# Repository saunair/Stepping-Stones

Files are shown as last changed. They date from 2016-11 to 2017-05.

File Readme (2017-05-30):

The code is launched in the master PC by the following commands in different terminals
roslaunch morpheus_skates stepping_stones.launch
rosrun morpheus_skates take_user_input.py
rosrun morpheus_skates shoe_size_input.py

Calibration routine:
roslaunch morpheus_skates calibration_arduino.py

The folder structure is created in a way that all the components are separate from each other
Arduino contains all the object oriented code that runs in each skate
CATKIN workspace contains all the ROS code 
Matlab contains the ROSBAGs, ROSBAG parsing scripts and some simulation files
Mechanical/CAD has all the CAD files of the skates 
Electrical Contains the PCB schematic and layouts used for power distribution and sensing

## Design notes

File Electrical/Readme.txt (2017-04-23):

Schematic and Layout Designs for Power distribution and sensing suite PCB.

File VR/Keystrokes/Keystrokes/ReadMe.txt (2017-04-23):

========================================================================
    CONSOLE APPLICATION : Keystrokes Project Overview
========================================================================

AppWizard has created this Keystrokes application for you.

This file contains a summary of what you will find in each of the files that
make up your Keystrokes application.

Keystrokes.vcxproj
    This is the main project file for VC++ projects generated using an Application Wizard.
    It contains information about the version of Visual C++ that generated the file, and
    information about the platforms, configurations, and project features selected with the
    Application Wizard.

Keystrokes.vcxproj.filters
    This is the filters file for VC++ projects generated using an Application Wizard. 
    It contains information about the association between the files in your project 
    and the filters. This association is used in the IDE to show grouping of files with
    similar extensions under a specific node (for e.g. ".cpp" files are associated with the
    "Source Files" filter).

Keystrokes.cpp
    This is the main application source file.

/////////////////////////////////////////////////////////////////////////////
Other standard files:

StdAfx.h, StdAfx.cpp
    These files are used to build a precompiled header (PCH) file
    named Keystrokes.pch and a precompiled types file named StdAfx.obj.

/////////////////////////////////////////////////////////////////////////////
Other notes:

AppWizard uses "TODO:" comments to indicate parts of the source code you
should add to or customize.

/////////////////////////////////////////////////////////////////////////////

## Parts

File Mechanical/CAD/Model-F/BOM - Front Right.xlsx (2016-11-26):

Bill of Materials for front half
Sl. No. | Item | Qty | Inventory | Remarks | Notes
1 | Base plate | 2 |  | Manufacture from stock plate
2 | Top plate | 2 |  | Manufacture from stock plate
3 | Force sensor foundation | 2 |  | Manufacture from stock plate
4 | Aux shaft | 2 |  | Manufacture from stock cylinder
5 | Motor-Gearbox adapter | 2 |  | Manufacture from stock cylinder
6 | Guide rail | 2 |  | 3D print
7 | Bearing mount | 2 |  | 3D print
8 | Gearbox mount | 2 |  | 3D print
9 | Ball caster mount | 6 |  | 3D print
10 | Force sensor locator | 2 |  | 3D print
11 | PCB mount | 2 |  | 3D print
12 | PCB | 2 |  | Manufacture (outsourced)
13 | Arduino | 2
14 | Wheel | 2 |  | Purchased - Banebots
15 | Wheel hub | 2 |  | Purchased - Banebots
16 | Gearbox | 2 |  | Purchased - Banebots
17 | Motor | 2 |  | Purchased - T-Motor
18 | Encoder | 2
19 | ESC | 2
20 | Force sensor | 4
21 | Ball casters | 6 |  | McMaster
22 | Bearing | 2 |  | McMaster
23 | Screw 10-32x1" | 20 |  |  | Including 2 extra for force sensor foundation
24 | Hex nut 10-32 | 12 |  |  | Including 2 extra for force sensor foundation
25 | Screw 4-40x3/8" | 42 |  |  | Ball caster mount
26 | Screw 4-40x1/2" | 28 |  |  | Guide rail, Bearing mount, Gearbox mount
26 | Grub screw 4-40x1/4" | 4 |  |  | Aux shaft
26 | Threaded inserts 4-40 | 70
Bill of Materials Back right half
Sl. No. | Item | Qty | Inventory | Remarks | Notes
1 | Base plate | 1 |  | Manufacture from stock plate | Might have to find more stock
2 | Top plate | 1 |  | Manufacture from stock plate
3 | Force sensor foundation | 1 |  | Manufacture from stock plate
4 | Aux shaft | 1 |  | Manufacture from stock cylinder
5 | Motor-Gearbox adapter | 1 |  | Manufacture from stock cylinder
6 | Guide rail | 1 |  | 3D print
7 | Bearing mount | 1 |  | 3D print
8 | Gearbox mount | 1 |  | 3D print
9 | Ball caster mount | 3 |  | 3D print
10 | Force sensor locator | 1 |  | 3D print
11 | Wheel | 1 |  | Purchased - Banebots
12 | Wheel hub | 1 |  | Purchased - Banebots
13 | Gearbox | 1 |  | Purchased - Banebots
14 | Motor | 1 |  | Purchased - T-Motor
15 | Encoder | 1
16 | ESC | 1
17 | Force sensor | 1
18 | Ball casters | 3 |  | McMaster
19 | Bearing | 1 |  | McMaster
20 | Screw 10-32x1" | 10 |  |  | Including 2 extra for force sensor foundation
21 | Hex nut 10-32 | 6 |  |  | Including 2 extra for force sensor foundation
22 | Screw 4-40x3/8" | 21 |  |  | Ball caster mount
23 | Screw 4-40x1/2" | 14 |  |  | Guide rail, Bearing mount, Gearbox mount
24 | Grub screw 4-40x1/4" | 2 |  |  | Aux shaft
25 | Threaded inserts 4-40 | 35
26 | IMU |  |  |  | Mounting needs to be discussed

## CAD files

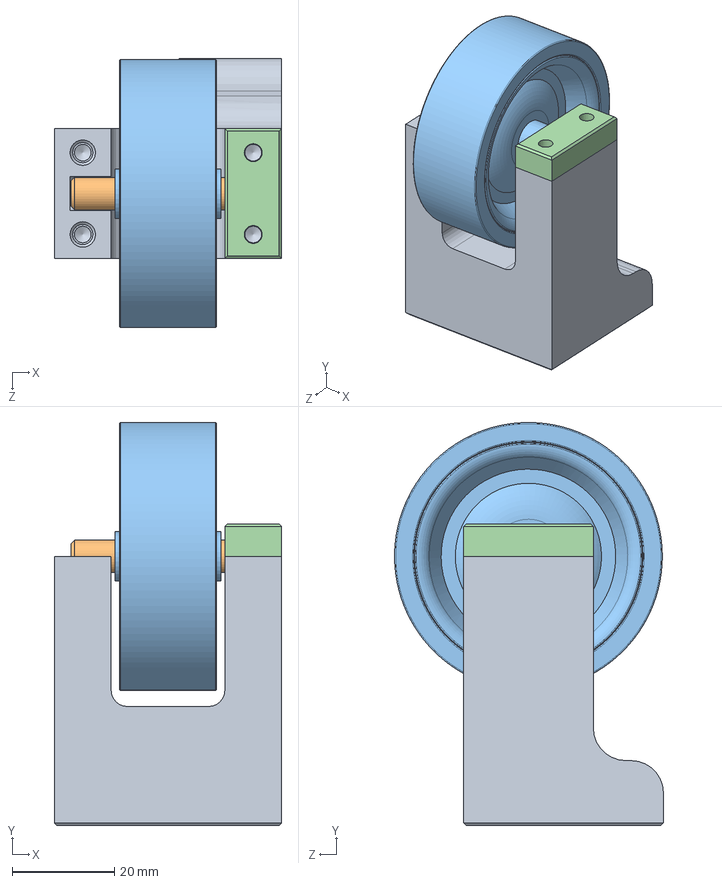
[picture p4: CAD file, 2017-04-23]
Mechanical/CAD/Model-S/ss_ms_v1_Skate_Wheel_Assembly_Mirrored.SLDASM
44.5 x 78.8 x 52.6 mm
ss_ms_v1_SkateWheelForkMirrored
ss_ms_v0_DowelPinShaft
ss_ms_v0_SkateWheel
ss_ms_v1_SkateWheelMount_Outer

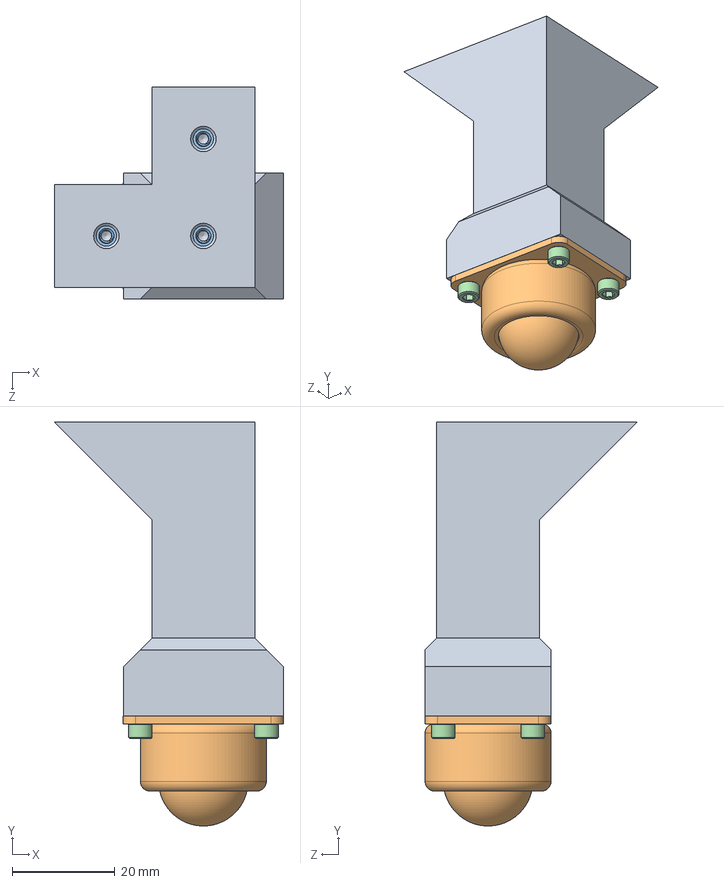
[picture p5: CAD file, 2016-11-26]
Mechanical/CAD/Model-F/Caster Supports/ss_mf_v1_BallCasterAssembly2.SLDASM
44.8 x 78.8 x 41.4 mm
ss_mf_v1_BallCasterMount2
ss_mf_v0_BallCaster
ss_mf_v0_ThreadedInsert440 x 7
ss_mf_v0_Screw_4-40x0.375 x 4

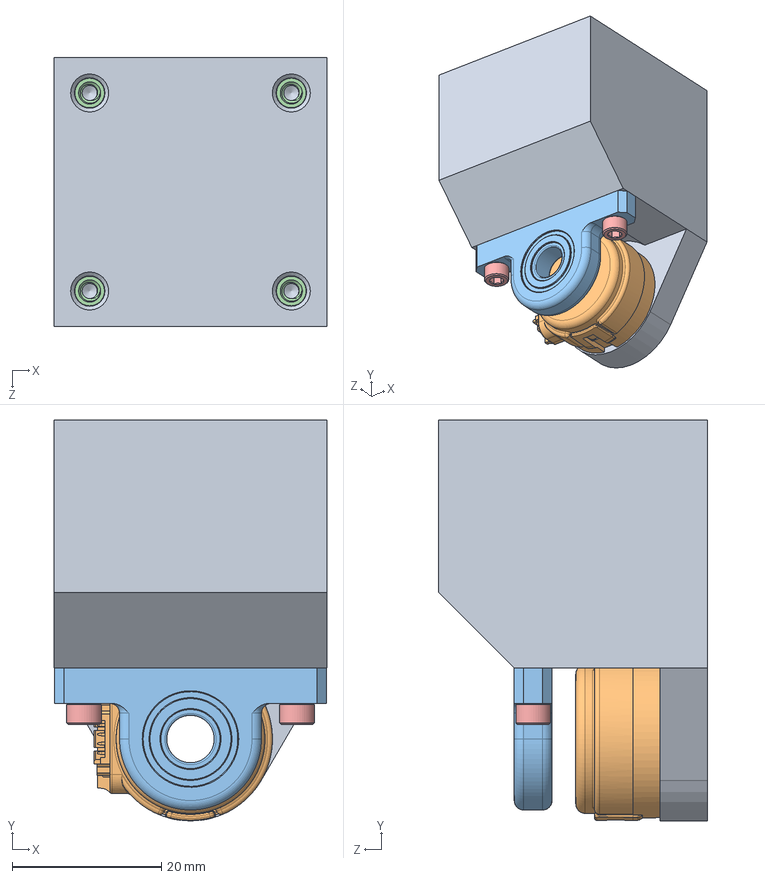
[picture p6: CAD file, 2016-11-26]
Mechanical/CAD/Model-F/Drive Train/ss_mf_v1_EncoderBearingAssembly.SLDASM
36.6 x 53.8 x 36.1 mm
ss_mf_v1_BearingMount
ss_mf_v0_Encoder
ss_mf_v0_Bearing
ss_mf_v0_ThreadedInsert440 x 6
ss_mf_v0_Screw_4-40x0.5 x 2

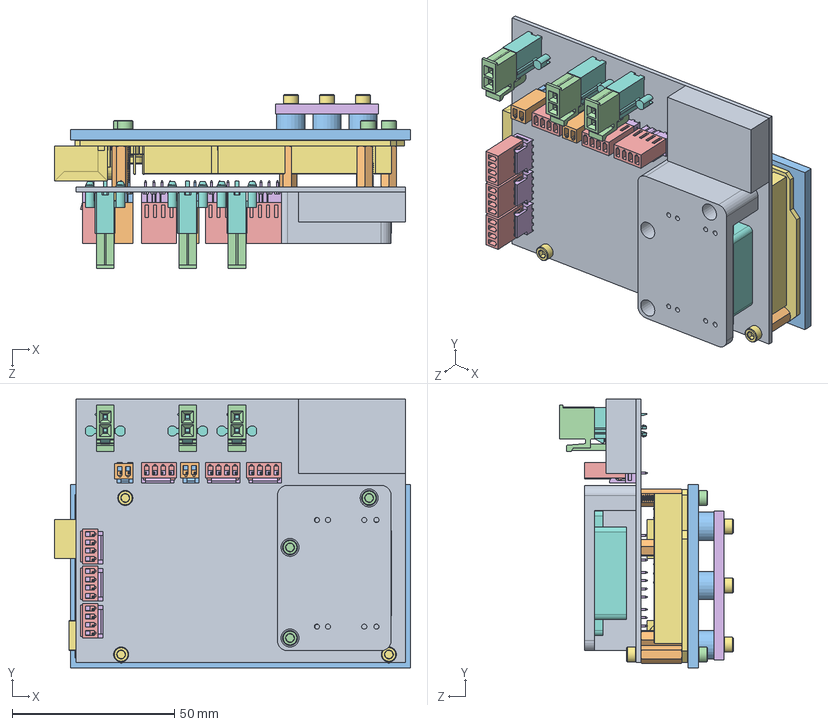
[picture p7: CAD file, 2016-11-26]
Mechanical/CAD/Model-F/PCB/ss_mf_v1_ArduinoMainboardAssembly.SLDASM
109.8 x 82.9 x 53.6 mm
ss_mf_v1_MainboardPCB
ss_mf_v0_ArduinoMega
UWS
ss_mf_v0_Standoff_4-40x0.5 x 6
ss_mf_v1_pcbMountP2
ss_mf_v0_Screw_4-40x0.5 x 7
ss_mf_v0_ThreadedInsert440 x 4
ss_mf_v1_pcbMountP1
ss_mf_v0_Screw_4-40x0.375 x 7
ss_mf_v0_IMU
ss_mf_v1_imuMount

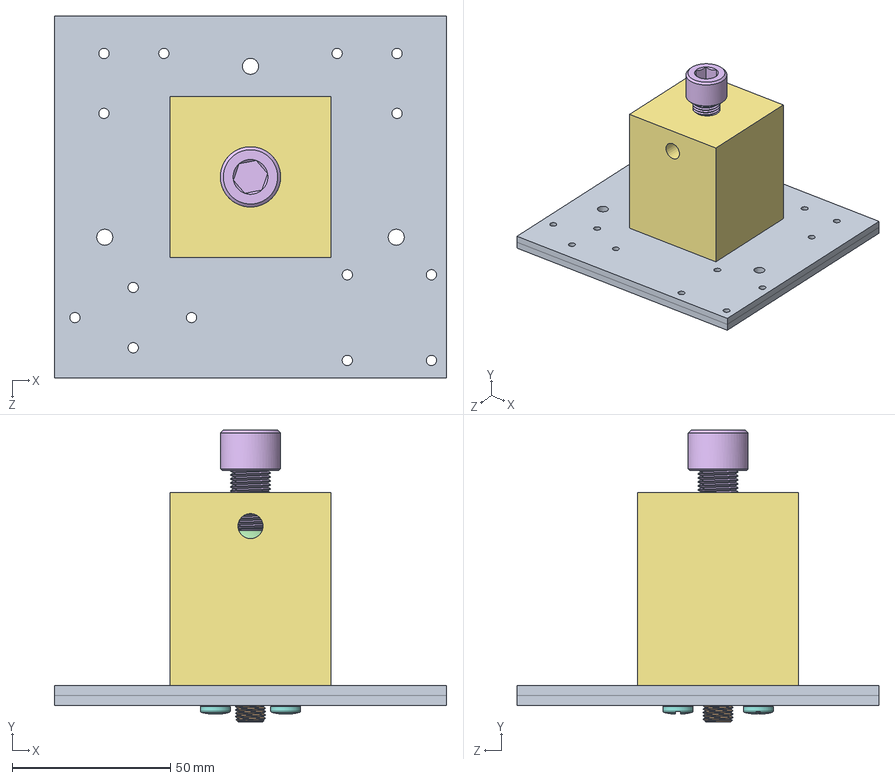
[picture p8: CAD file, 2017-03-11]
Mechanical/CAD/Force Calibration Rig/Rear Force Calibration Rig.SLDASM
123.8 x 92.2 x 114.3 mm
ss_mf_v1_BasePlateBack x 2
92620A654_HIGH-STRENGTH GRADE 8 STEEL CAP SCREW
92141A031_TYPE 18-8 STAINLESS STEEL FLAT WASHER x 2
92949A749_18-8 SS BUTTON-HEAD SOCKET CAP SCREW
9573K620_MEDIUM LOAD CHROME-SILICON STEEL DIE SPRING
92196A384_18-8 STAINLESS STEEL SOCKET HEAD CAP SCREW
Rear Skate Rig Block
90283A831_ZINC-PLTD STL PAN HEAD SLOTTED MACHINE SCREW x 4

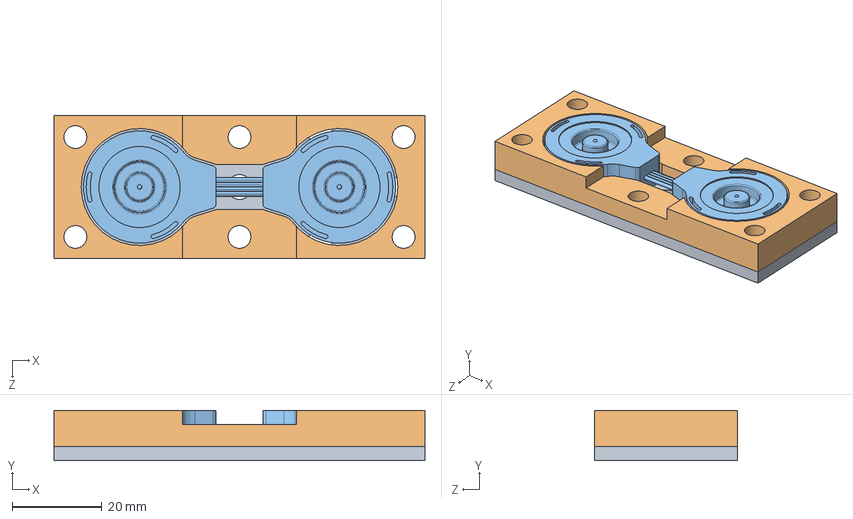
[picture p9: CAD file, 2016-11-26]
Mechanical/CAD/Model-F/Force Sensing/ss_mf_v1_DualForceAssembly.SLDASM
82.5 x 11.2 x 31.8 mm
ss_mf_v1_ForceSensorFoundationDual
ss_mf_v1_ForceSensorLocatorDual
ss_mf_v0_ForceSensor x 2

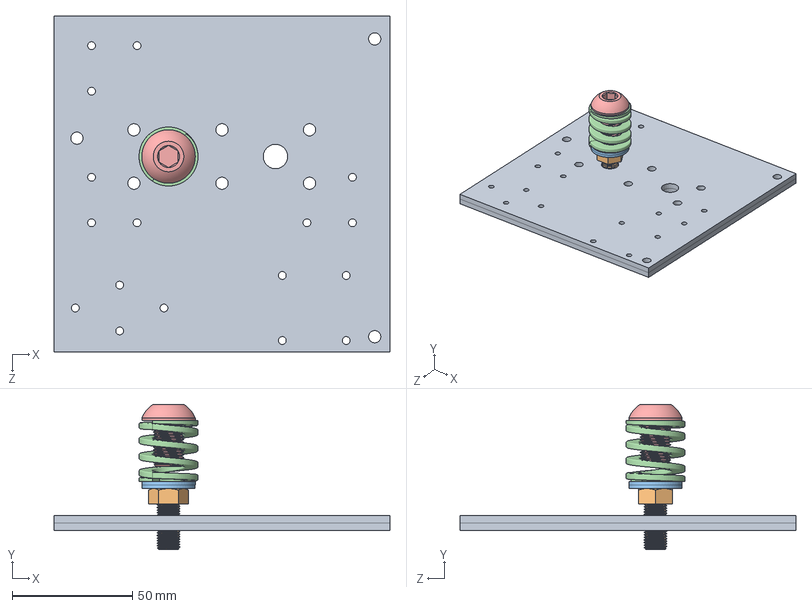
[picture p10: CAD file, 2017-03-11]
Mechanical/CAD/Force Calibration Rig/Force Calibration Rig.SLDASM
139.7 x 60.4 x 139.7 mm
ss_mf_v1_BasePlate x 2
92620A654_HIGH-STRENGTH GRADE 8 STEEL CAP SCREW
92141A031_TYPE 18-8 STAINLESS STEEL FLAT WASHER x 2
9573K620_MEDIUM LOAD CHROME-SILICON STEEL DIE SPRING
92949A749_18-8 SS BUTTON-HEAD SOCKET CAP SCREW

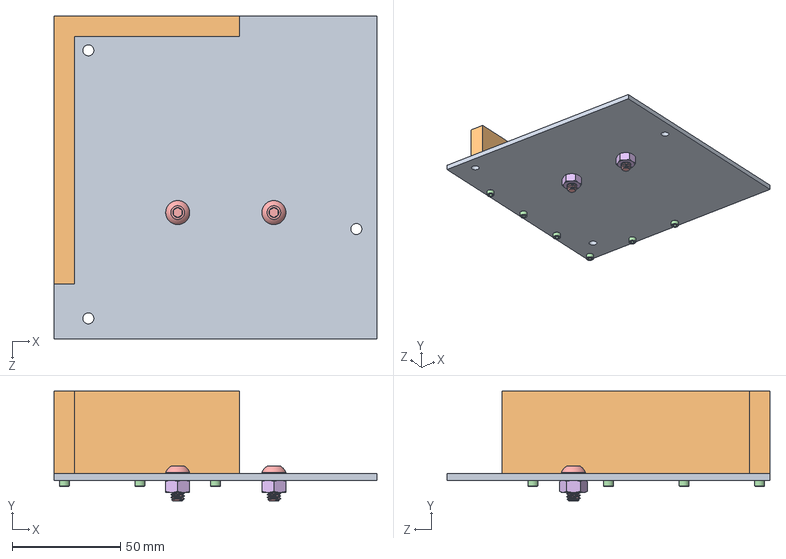
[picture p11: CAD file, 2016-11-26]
Mechanical/CAD/Model-F/ss_mf_v1_Top_Plate_Assembly.SLDASM
149.2 x 50.8 x 149.2 mm
ss_mf_v1_TopPlate
ss_mf_v1_GuideRail
ss_mf_v0_ThreadedInsert440 x 6
ss_mf_v0_Screw_4-40x0.375 x 6
ss_mf_v0_Screw_1_4-20x0.5 x 2
ss_mf_v0_HexNut_1_4-20 x 2

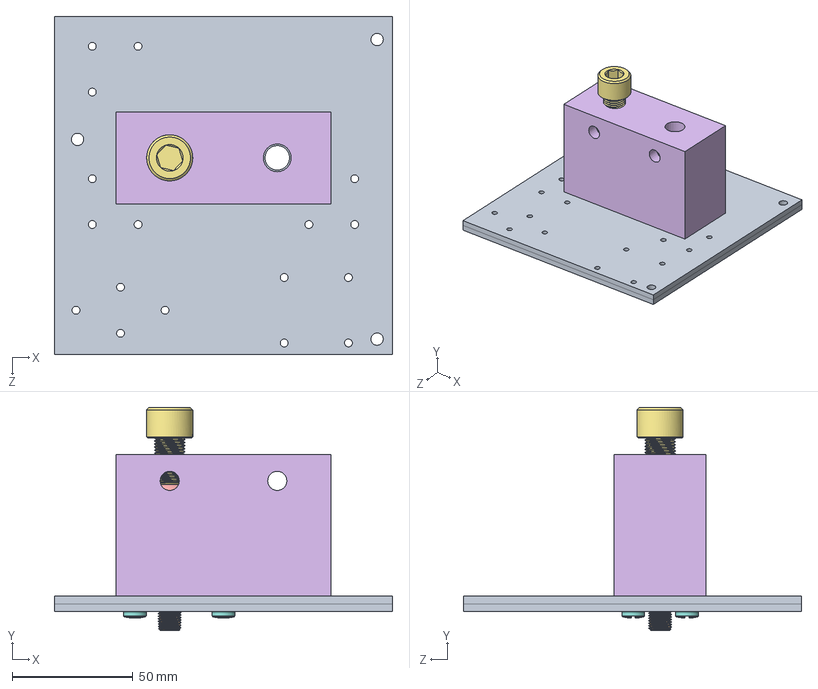
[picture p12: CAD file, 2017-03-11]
Mechanical/CAD/Force Calibration Rig/Front Force Calibration Rig.SLDASM
139.7 x 92.2 x 139.7 mm
ss_mf_v1_BasePlate x 2
92620A654_HIGH-STRENGTH GRADE 8 STEEL CAP SCREW
92141A031_TYPE 18-8 STAINLESS STEEL FLAT WASHER x 2
9573K620_MEDIUM LOAD CHROME-SILICON STEEL DIE SPRING
92949A749_18-8 SS BUTTON-HEAD SOCKET CAP SCREW
Front Skate Rig Block
92196A384_18-8 STAINLESS STEEL SOCKET HEAD CAP SCREW
90283A831_ZINC-PLTD STL PAN HEAD SLOTTED MACHINE SCREW x 4

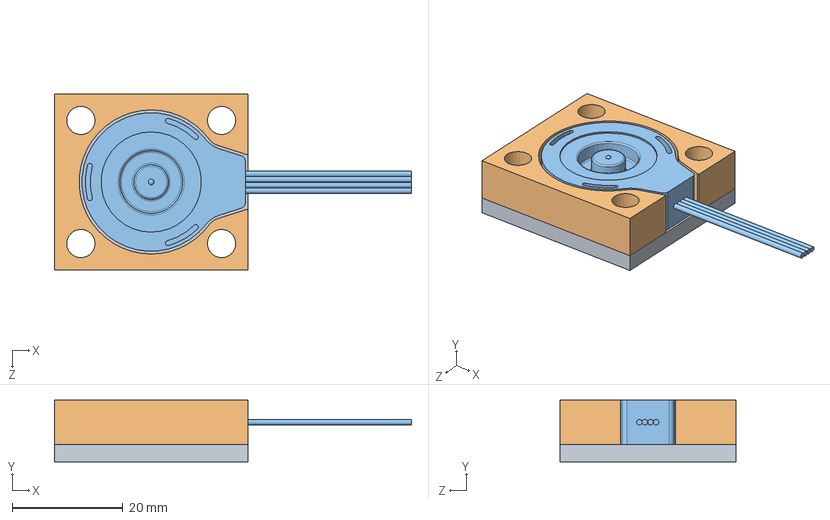
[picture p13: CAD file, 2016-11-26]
Mechanical/CAD/Model-F/Force Sensing/ss_mf_v1_SingleForceAssembly.SLDASM
64.5 x 11.2 x 31.8 mm
ss_mf_v1_ForceSensorFoundationSingle
ss_mf_v1_ForceSensorLocatorSingle
ss_mf_v0_ForceSensor

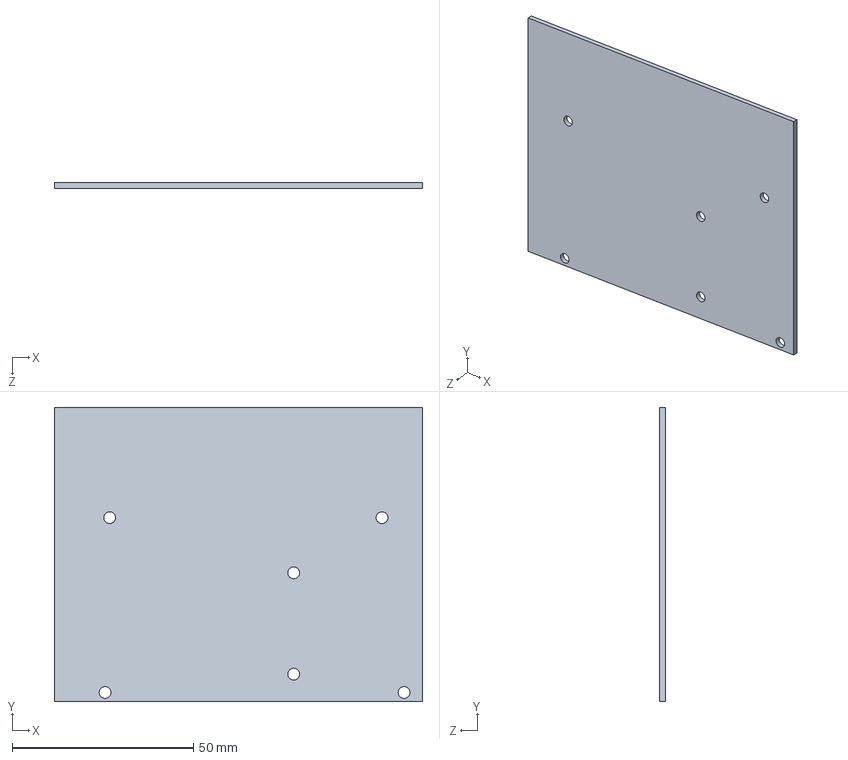
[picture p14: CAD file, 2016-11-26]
Mechanical/CAD/Model-F/PCB/ss_mf_v1_MainboardPCB.SLDPRT
101.6 x 81.3 x 1.52 mm

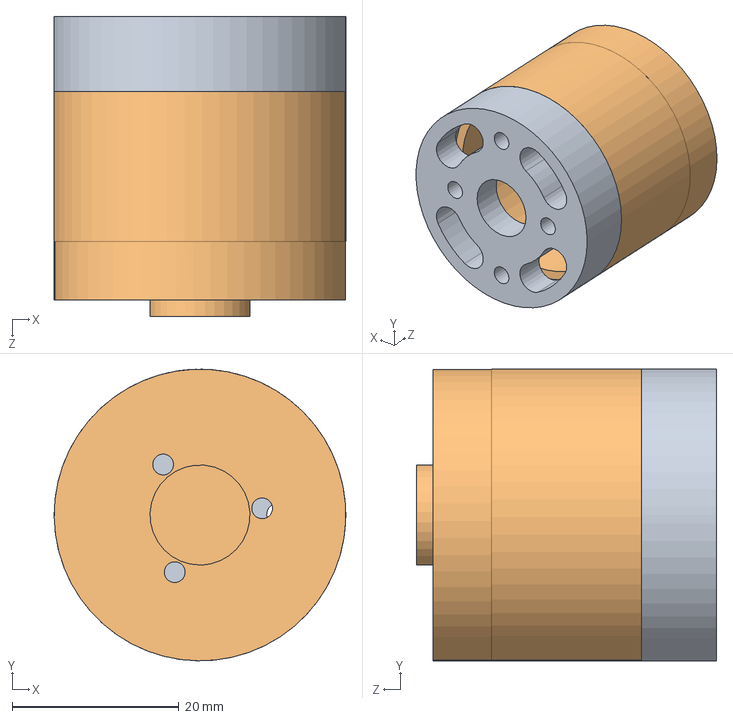
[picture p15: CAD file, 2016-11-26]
Mechanical/CAD/Model-F/Drive Train/ss_mf_v0_Motor.SLDASM
35.0 x 35.0 x 36.0 mm
ss_mf_v0_MotorBack
ss_mf_v0_MotorFront

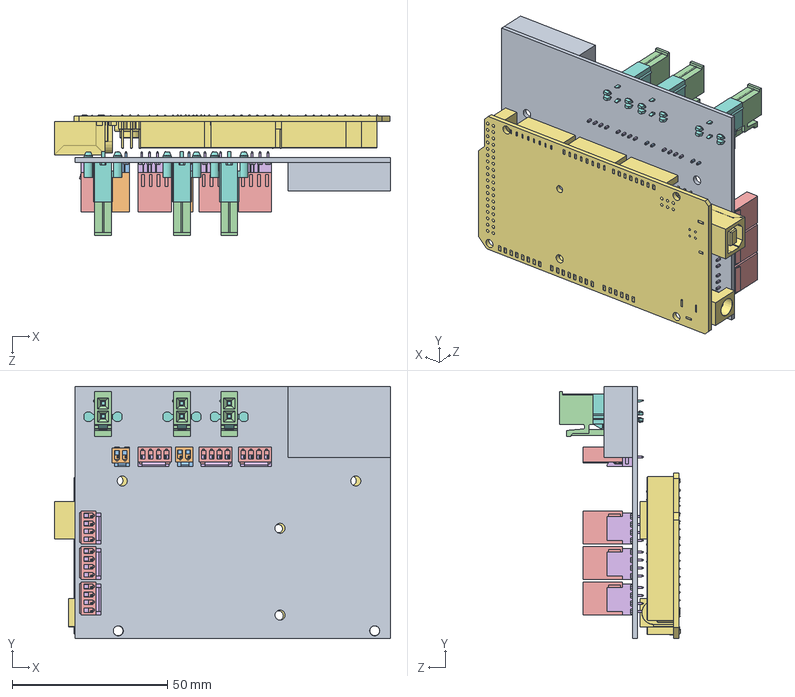
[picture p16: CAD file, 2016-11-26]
Mechanical/CAD/Model-F/PCB/ss_mf_v1_ArduinoMainboard.SLDASM
108.2 x 81.3 x 38.9 mm
ss_mf_v1_MainboardPCB
ss_mf_v0_ArduinoMega
UWS

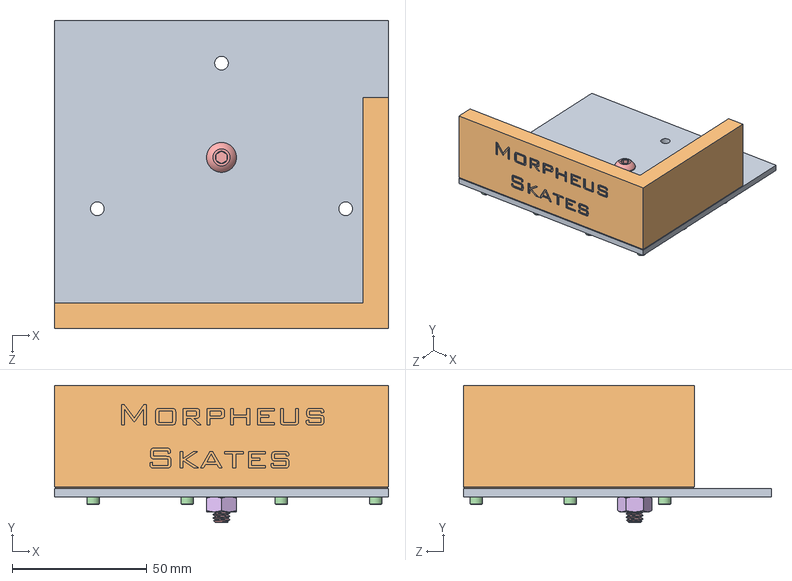
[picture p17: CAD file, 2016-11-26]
Mechanical/CAD/Model-F/ss_mf_v1_BL_Top_Plate_Assembly.SLDASM
123.8 x 50.8 x 114.3 mm
ss_mf_v1_TopPlateBack
ss_mf_v1_GuideRail_BL
ss_mf_v0_ThreadedInsert440 x 6
ss_mf_v0_Screw_4-40x0.5 x 6
ss_mf_v0_Screw_1_4-20x0.5
ss_mf_v0_HexNut_1_4-20

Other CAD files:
Mechanical/CAD/Model-S/ss_ms_v1_Skate_Wheel_Assembly.SLDASM
Mechanical/CAD/Model-F/Caster Supports/ss_mf_v1_BallCasterAssembly.SLDASM
Mechanical/CAD/Model-F/ss_mf_v1_FR_Top_Plate_Assembly.SLDASM
Mechanical/CAD/Model-F/Drive Train/ss_mf_v1_DriveTrainAssembly.SLDASM
Mechanical/CAD/Force Calibration Rig/90283A831_ZINC-PLTD STL PAN HEAD SLOTTED MACHINE SCREW.SLDPRT
Mechanical/CAD/Force Calibration Rig/91841A195_TYPE 18-8 STAINLESS STEEL HEX NUT.SLDPRT
Mechanical/CAD/Force Calibration Rig/92141A031_TYPE 18-8 STAINLESS STEEL FLAT WASHER.SLDPRT
Mechanical/CAD/Force Calibration Rig/92196A384_18-8 STAINLESS STEEL SOCKET HEAD CAP SCREW.SLDPRT
Mechanical/CAD/Force Calibration Rig/92210A304_18-8 STAINLESS STEEL FLAT-HEAD SCKT CAP SCREW.SLDPRT
Mechanical/CAD/Force Calibration Rig/92620A654_HIGH-STRENGTH GRADE 8 STEEL CAP SCREW.SLDPRT
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

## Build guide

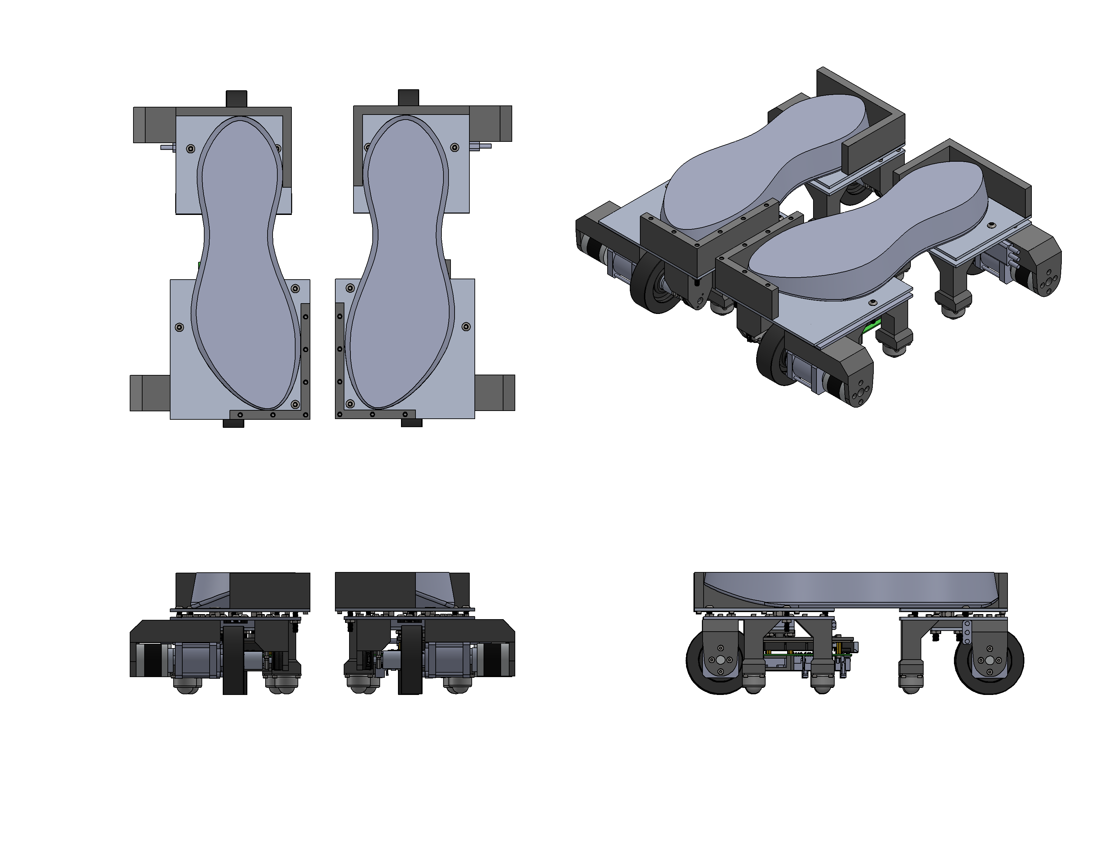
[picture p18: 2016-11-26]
Mechanical/CAD/Model-F/ss_mf_v1_Shoe_Test_Assembly.PNG

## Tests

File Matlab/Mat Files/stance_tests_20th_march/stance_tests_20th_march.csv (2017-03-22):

Time | LeftNormalFrontOuter | LeftNormalFrontInner | LeftNormalRear | RightNormalFrontOuter | RightNormalFrontInner | RightNormalRear | RightNormalTotal | LeftNormalTotal | NormalTotal | Label
-1490064341.57929 | 0.0568256229162216 | 0.121759116649628 | 0.313521653413773 | 0.00944731291383505 | 0.183949649333954 | 0.327496975660324 | 0.520893931388855 | 0.492106378078461 | 1.01300036907196 | 1
-1490064341.57929 | 0.0553924106061459 | 0.121759116649628 | 0.313521653413773 | 0.0108032403513789 | 0.185449823737144 | 0.325034290552139 | 0.521287322044373 | 0.490673154592514 | 1.01196050643921 | 1
-1490064341.57929 | 0.0568256229162216 | 0.123117178678513 | 0.31218209862709 | 0.00944731291383505 | 0.186949983239174 | 0.322571575641632 | 0.518968880176544 | 0.492124885320663 | 1.01109373569489 | 1
-1490064341.57929 | 0.0553924106061459 | 0.123117178678513 | 0.313521653413773 | 0.0108032403513789 | 0.188450157642365 | 0.320108860731125 | 0.519362270832062 | 0.492031216621399 | 1.01139354705811 | 1
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

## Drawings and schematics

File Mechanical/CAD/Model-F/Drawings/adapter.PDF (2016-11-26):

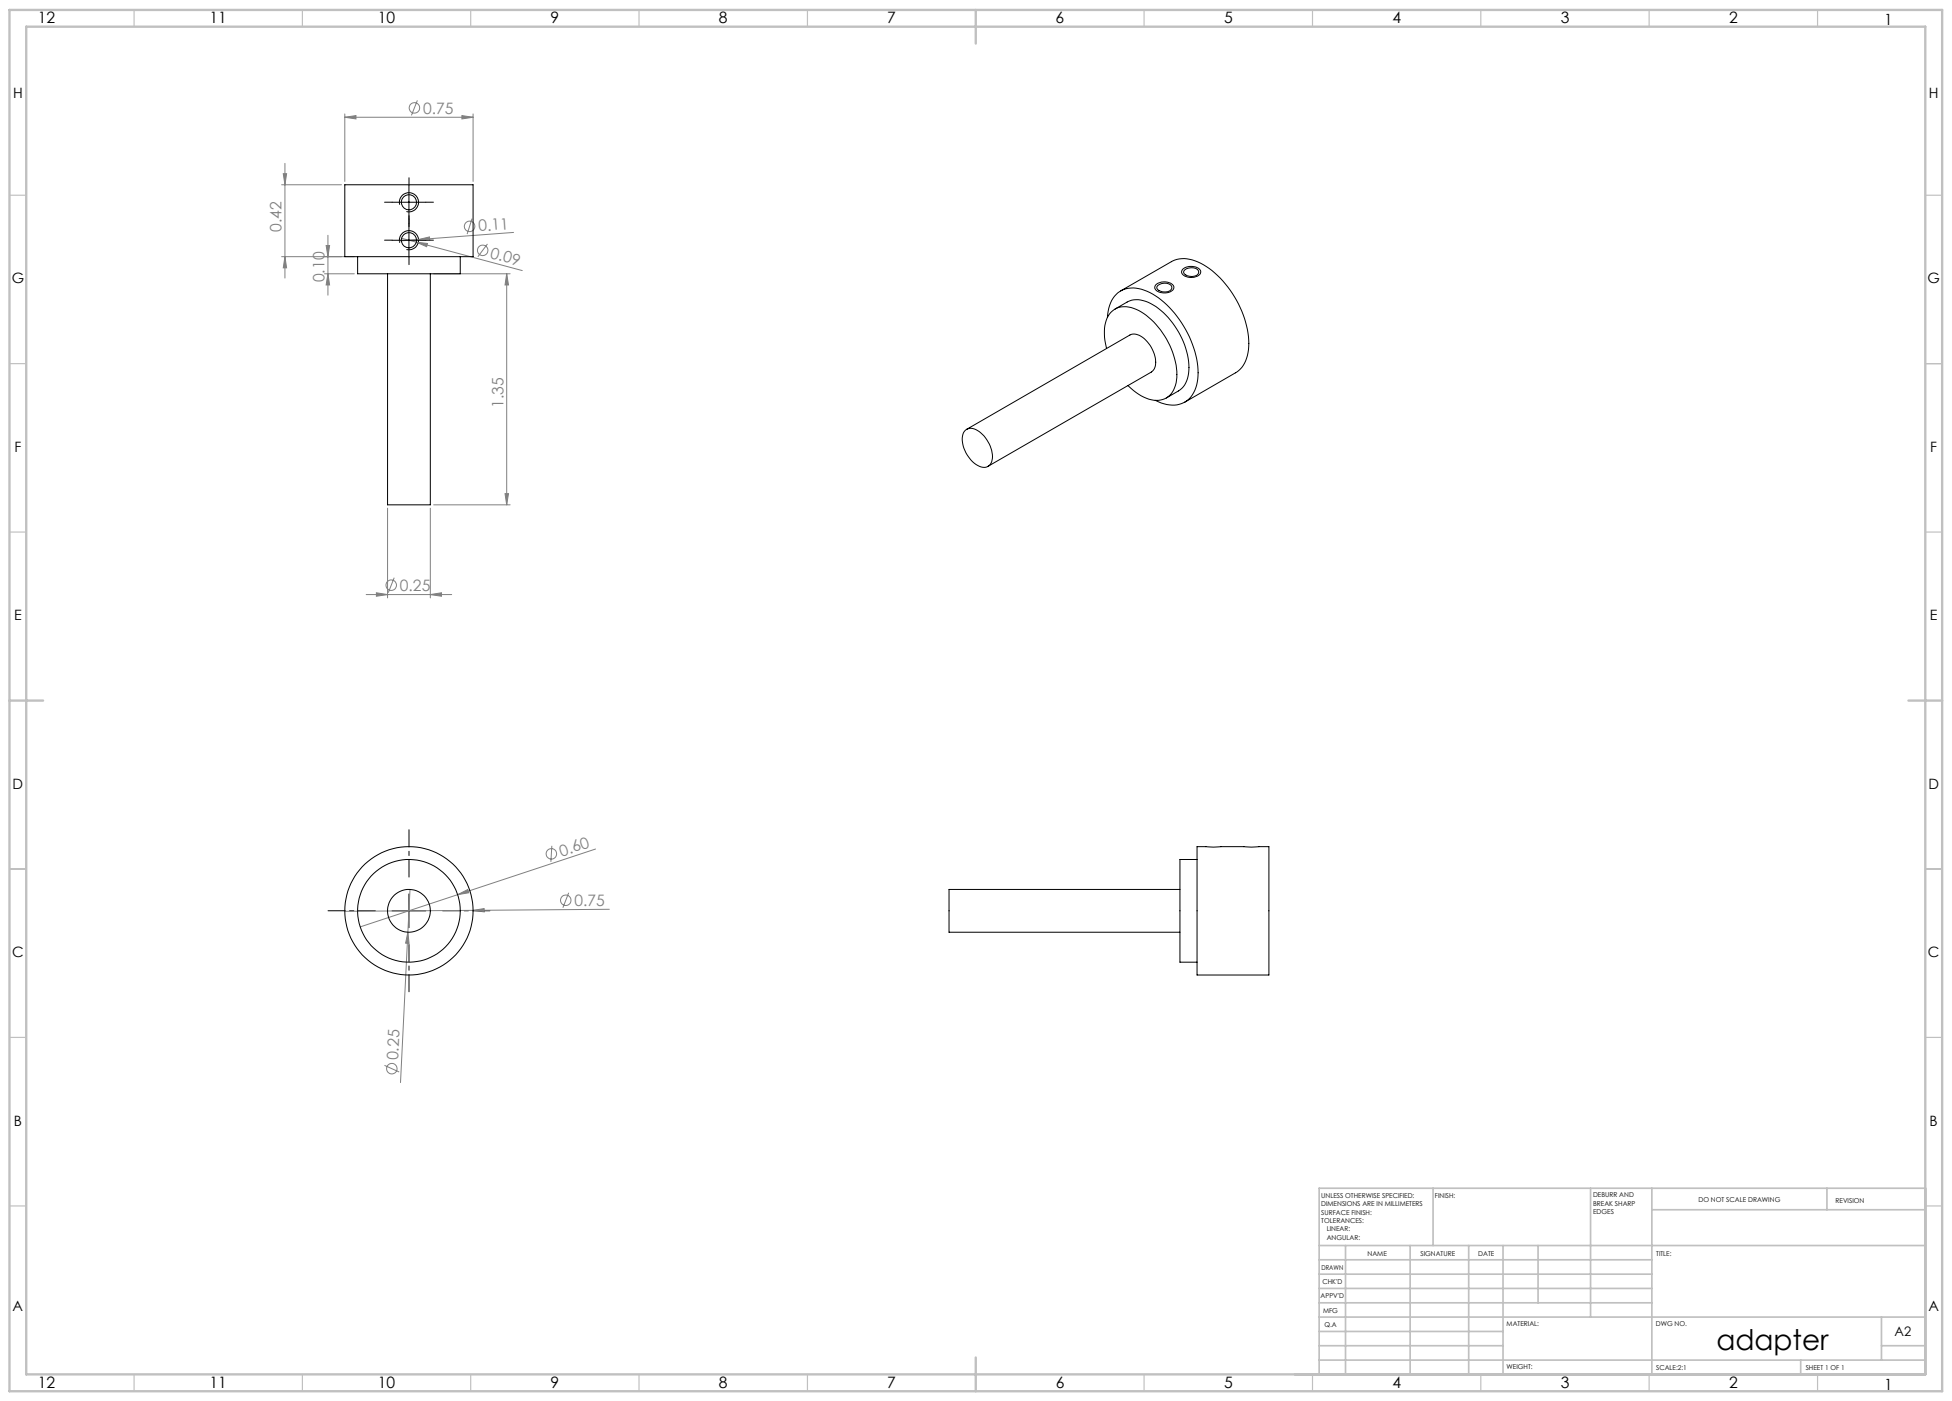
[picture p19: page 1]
SCALE:2:1; SHEET 1 OF 1

UNLESS OTHERWISE SPECIFIED: DIMENSIONS ARE IN MILLIMETERS SURFACE FINISH: TOLERANCES: LINEAR: ANGULAR: | FINISH: | DEBURR AND BREAK SHARP EDGES | DO NOT SCALE DRAWING | REVISION

NAME | SIGNATURE | DATE | | | | TITLE:

DRAWN
CHK'D
APPV'D
MFG
Q.A | | | | MATERIAL: | DWG NO. adapter | A2

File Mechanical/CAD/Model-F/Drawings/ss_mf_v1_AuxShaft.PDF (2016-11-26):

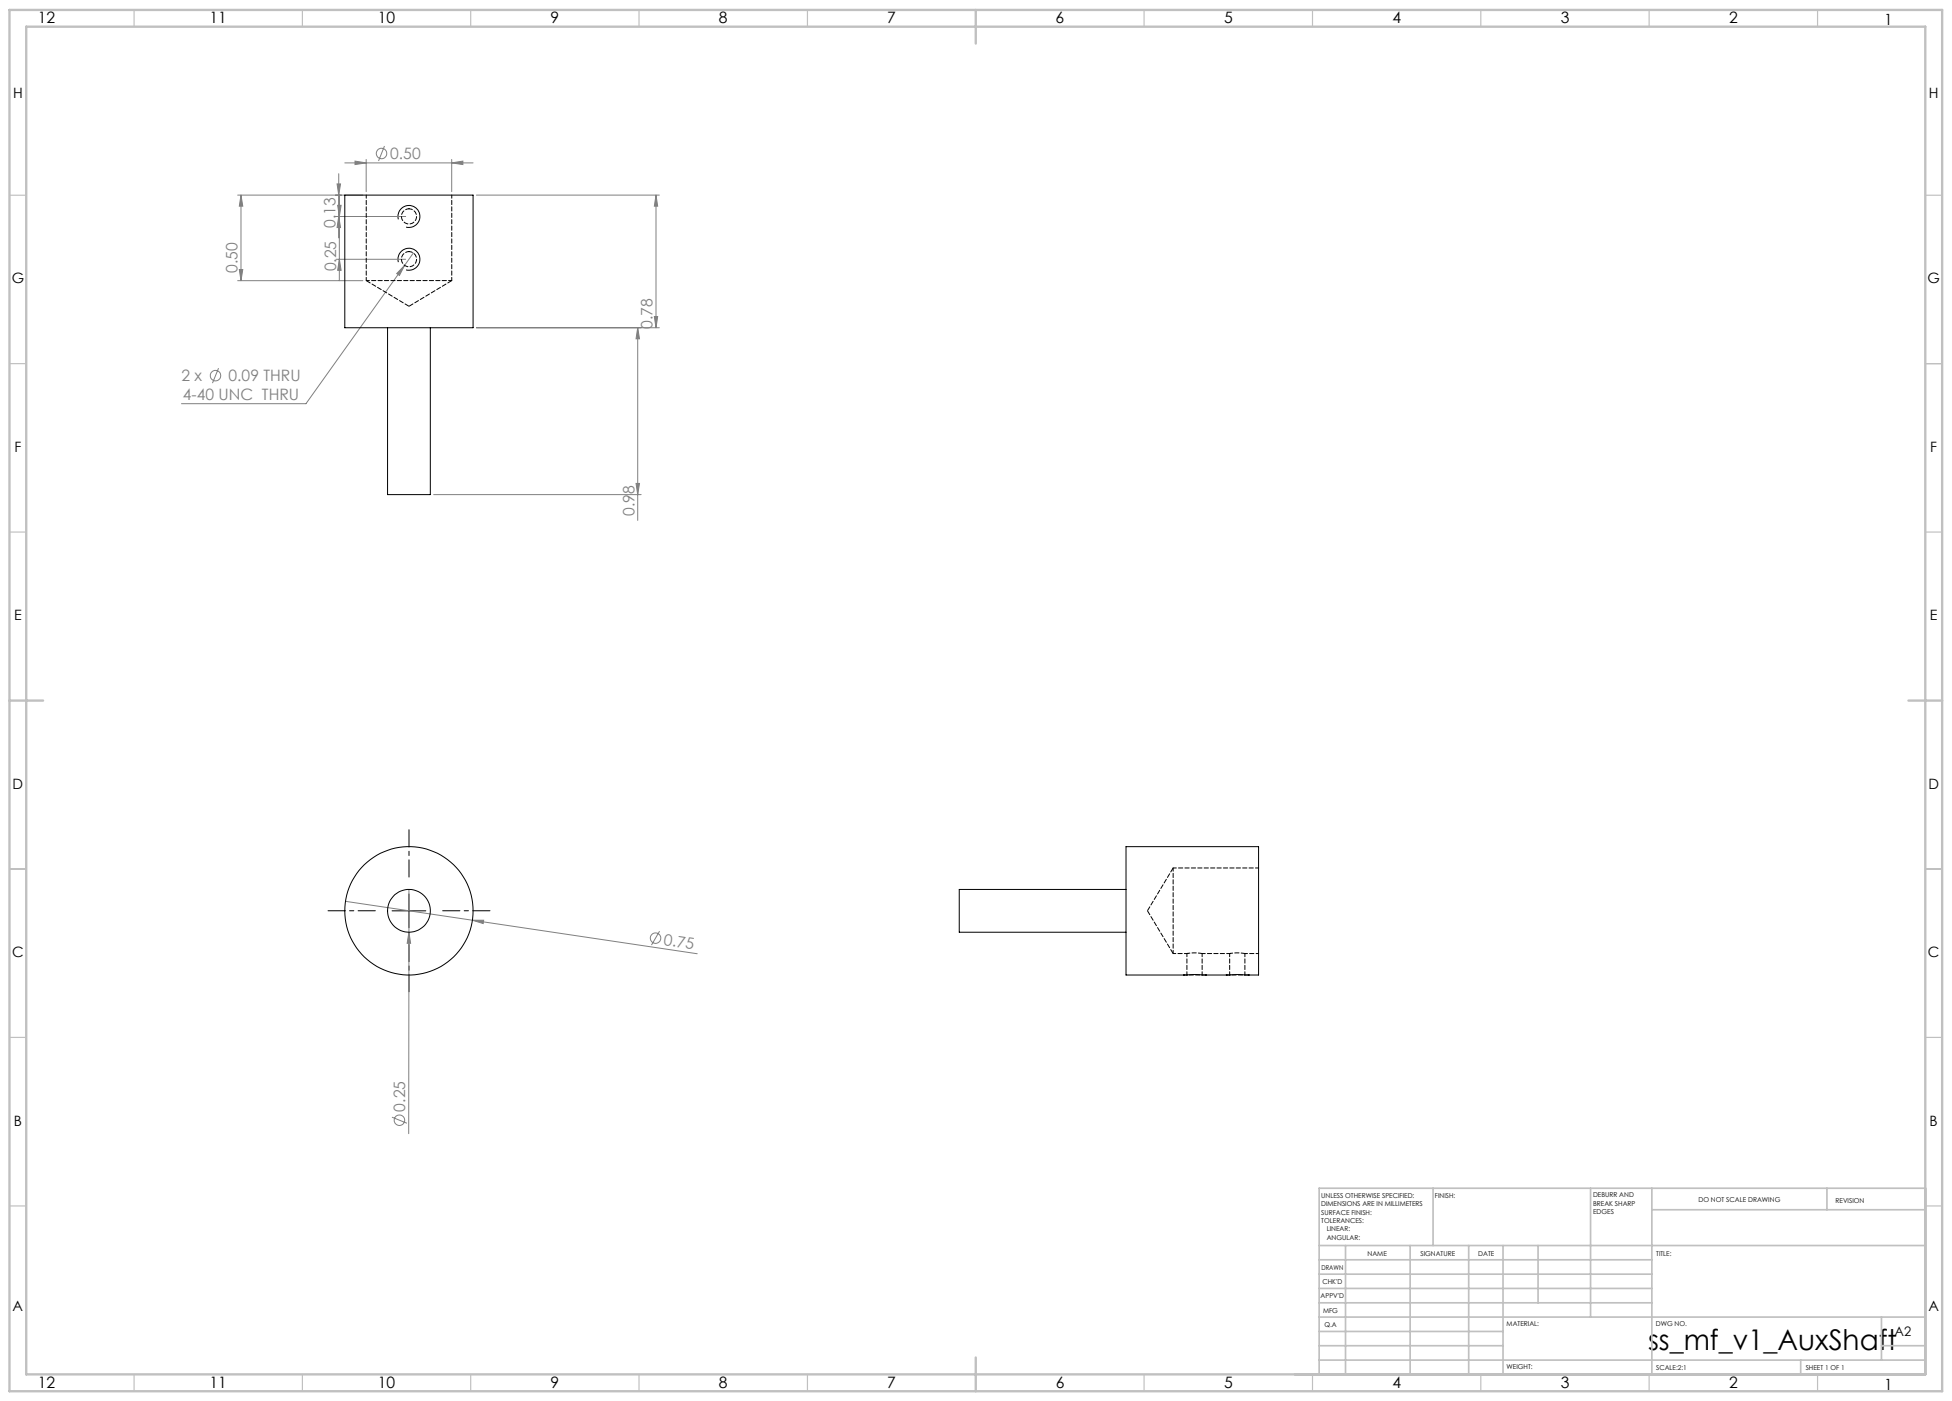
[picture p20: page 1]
0.09 THRU; 4-40 UNC THRU; FINISH:; DEBURR AND; BREAK SHARP; DO NOT SCALE DRAWING; REVISION; SCALE:2:1; SHEET 1 OF 1

UNLESS OTHERWISE SPECIFIED:
DIMENSIONS ARE IN MILLIMETERS
SURFACE FINISH:
TOLERANCES:
LINEAR:
ANGULAR:

NAME | SIGNATURE | DATE | | | | TITLE:

DRAWN
CHK'D
APPV'D
MFG
Q.A | | | | MATERIAL: ss_mf_v1_AuxShaft | DWG NO. | A2

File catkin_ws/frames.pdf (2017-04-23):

Recorded at time: 1490757470.691

Broadcaster: /openni_tracker
Average rate: 30.178 Hz

Most recent transform: 1490757470.685 ( 0.007 sec old)

Buffer length: 4.971 sec

Buffer length: 4.970 sec

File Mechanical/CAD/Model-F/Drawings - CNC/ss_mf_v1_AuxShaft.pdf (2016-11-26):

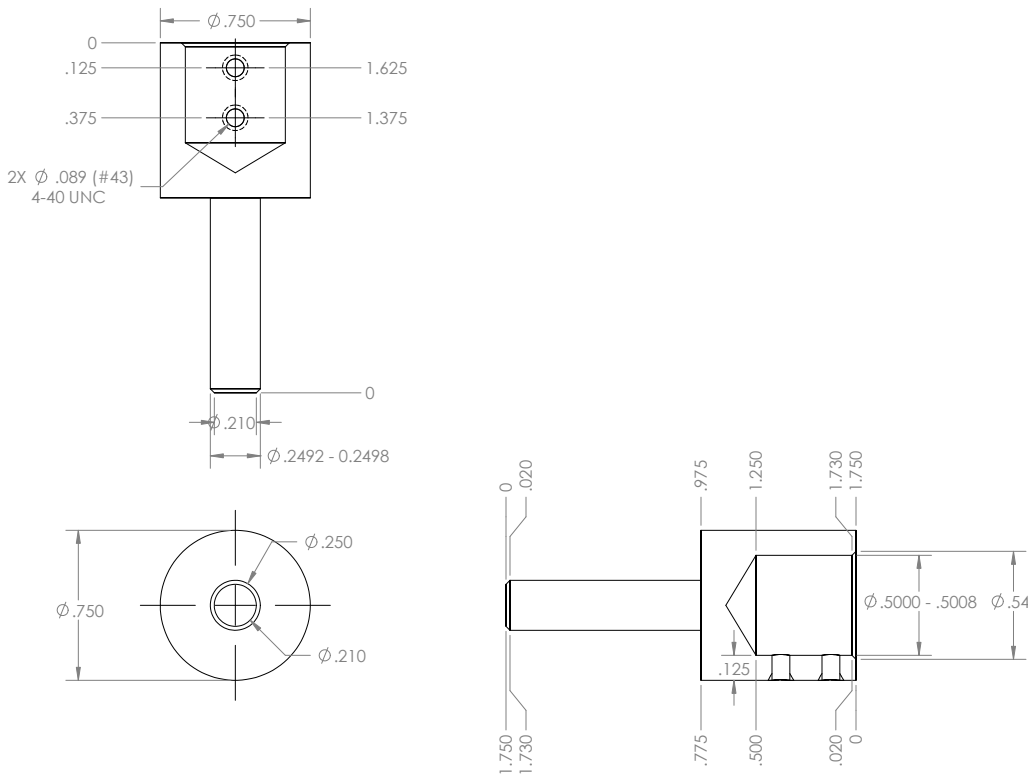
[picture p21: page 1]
4-40 UNC

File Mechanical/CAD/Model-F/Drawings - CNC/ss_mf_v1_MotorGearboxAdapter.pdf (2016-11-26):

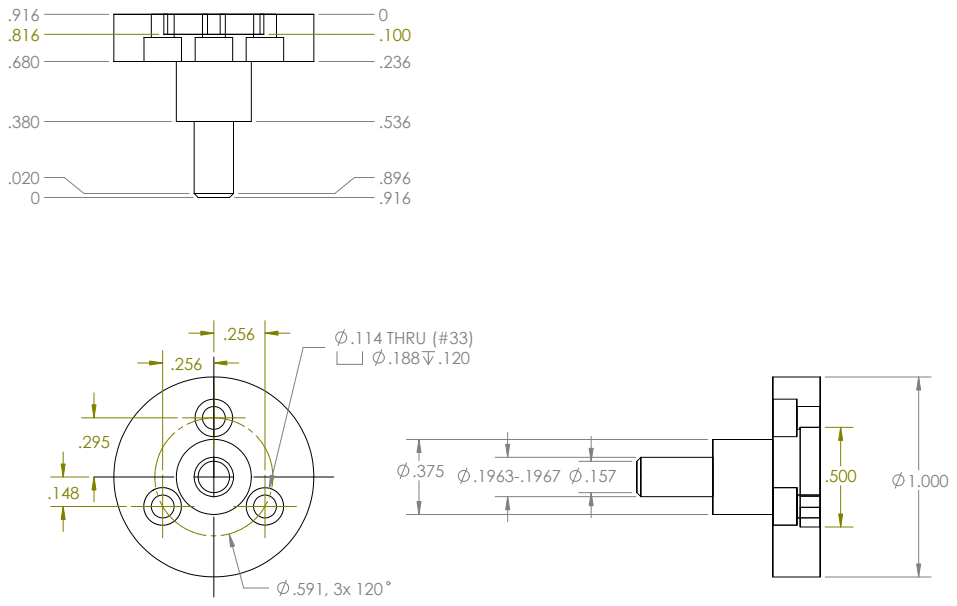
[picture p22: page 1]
.114 THRU (#33)

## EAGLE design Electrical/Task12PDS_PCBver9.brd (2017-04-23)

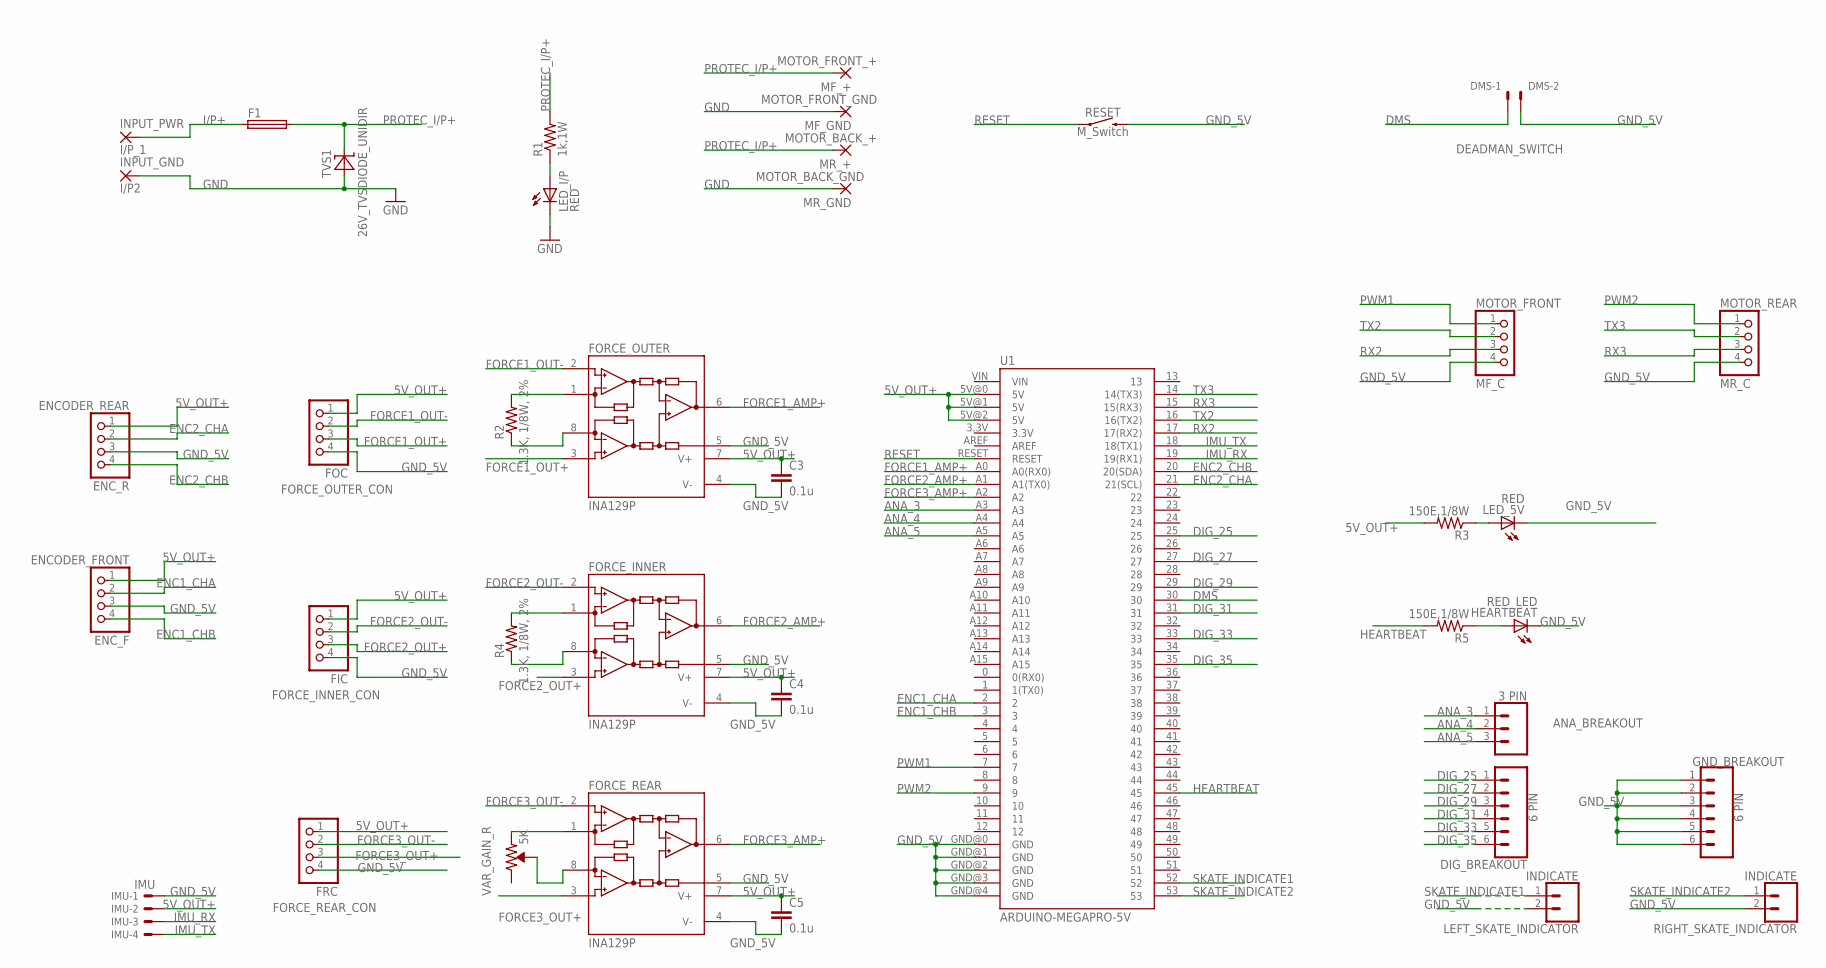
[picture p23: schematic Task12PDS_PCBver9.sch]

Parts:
ANA_BREAKOUT: 3 PIN; 1X03
C3, C4, C5: 0.1u; C1206
DIG_BREAKOUT: 6 PIN; 1X06
DMS: DEADMAN_SWITCH; 22-23-2021
ENCODER_FRONT: ENC_F; 1X04/90
ENCODER_REAR: ENC_R; 1X04/90
F1: FASTBLOW_FUSE_10A; TE5
FORCE_INNER: INA129P; DIL08
FORCE_INNER_CON: FIC; 1X04/90
FORCE_OUTER: INA129P; DIL08
FORCE_OUTER_CON: FOC; 1X04/90
FORCE_REAR: INA129P; DIL08
FORCE_REAR_CON: FRC; 1X04/90
GND_BREAKOUT: 6 PIN; 1X06
HEARTBEAT: RED_LED; 1206
IMU: IMU; 22-23-2041
INPUT_GND: I/P2; 3,81/1,1
INPUT_PWR: I/P_1; 3,81/1,1
LED_5V: RED; 1206
LED_I/P: RED; 1206
LEFT_SKATE_INDICATOR: INDICATE; 1X02
MF_+: MOTOR_FRONT_+; 3,81/1,1
MF_GND: MOTOR_FRONT_GND; 3,81/1,1
MOTOR_FRONT: MF_C; 1X04/90
MOTOR_REAR: MR_C; 1X04/90
MR_+: MOTOR_BACK_+; 3,81/1,1
MR_GND: MOTOR_BACK_GND; 3,81/1,1
R1: 1k,1W; M1206
R2, R4: 1.3K, 1/8W, 2%; M1206
R3, R5: 150E,1/8W; M1206
RESET: M_Switch; TACTILE_SWITCH_PTH_6.0MM
RIGHT_SKATE_INDICATOR: INDICATE; 1X02
TVS1: 26V_TVSDIODE_UNIDIR; DO214AC
U1: ARDUINO-MEGAPRO-5V; ARDUINO_MEGA-PRO-5V
VAR_GAIN_R: 5K; TRIMPOT-PTH-3386U

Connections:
5V_OUT+: C3.1, C4.1, C5.1, ENCODER_FRONT.1, ENCODER_REAR.1, FORCE_INNER.7 (V+), FORCE_INNER_CON.1, FORCE_OUTER.7 (V+), FORCE_OUTER_CON.1, FORCE_REAR.7 (V+), FORCE_REAR_CON.1, IMU.2, R3.2, U1.5V@0 (5V), U1.5V@1 (5V), U1.5V@2 (5V)
ANA_3: ANA_BREAKOUT.1, U1.A3
ANA_4: ANA_BREAKOUT.2, U1.A4
ANA_5: ANA_BREAKOUT.3, U1.A5
DIG_25: DIG_BREAKOUT.1, U1.25
DIG_27: DIG_BREAKOUT.2, U1.27
DIG_29: DIG_BREAKOUT.3, U1.29
DIG_31: DIG_BREAKOUT.4, U1.31
DIG_33: DIG_BREAKOUT.5, U1.33
DIG_35: DIG_BREAKOUT.6, U1.35
DMS: DMS.1, U1.30
ENC1_CHA: ENCODER_FRONT.2, U1.2
ENC1_CHB: ENCODER_FRONT.4, U1.3
ENC2_CHA: ENCODER_REAR.2, U1.21 (21(SCL))
ENC2_CHB: ENCODER_REAR.4, U1.20 (20(SDA))
FORCE1_AMP+: FORCE_OUTER.6 (OUT), U1.A0 (A0(RX0))
FORCE1_OUT+: FORCE_OUTER.3 (+IN), FORCE_OUTER_CON.3
FORCE1_OUT-: FORCE_OUTER.2 (-IN), FORCE_OUTER_CON.2
FORCE2_AMP+: FORCE_INNER.6 (OUT), U1.A1 (A1(TX0))
FORCE2_OUT+: FORCE_INNER.3 (+IN), FORCE_INNER_CON.3
FORCE2_OUT-: FORCE_INNER.2 (-IN), FORCE_INNER_CON.2
FORCE3_AMP+: FORCE_REAR.6 (OUT), U1.A2
FORCE3_OUT+: FORCE_REAR.3 (+IN), FORCE_REAR_CON.3
FORCE3_OUT-: FORCE_REAR.2 (-IN), FORCE_REAR_CON.2
GND: INPUT_GND.1, LED_I/P.C, MF_GND.1, MR_GND.1, TVS1.A
GND_5V: C3.2, C4.2, C5.2, DMS.2, ENCODER_FRONT.3, ENCODER_REAR.3, FORCE_INNER.4 (V-), FORCE_INNER.5 (REF), FORCE_INNER_CON.4, FORCE_OUTER.4 (V-), FORCE_OUTER.5 (REF), FORCE_OUTER_CON.4, FORCE_REAR.4 (V-), FORCE_REAR.5 (REF), FORCE_REAR_CON.4, GND_BREAKOUT.1, GND_BREAKOUT.2, GND_BREAKOUT.3, GND_BREAKOUT.4, GND_BREAKOUT.5, GND_BREAKOUT.6, HEARTBEAT.C, IMU.1, LED_5V.C, LEFT_SKATE_INDICATOR.2, MOTOR_FRONT.4, MOTOR_REAR.4, RESET.3 (2), RIGHT_SKATE_INDICATOR.2, U1.GND@0 (GND), U1.GND@1 (GND), U1.GND@2 (GND), U1.GND@3 (GND), U1.GND@4 (GND)
HEARTBEAT: R5.2, U1.45
I/P+: F1.1, INPUT_PWR.1
IMU_RX: IMU.3, U1.19 (19(RX1))
IMU_TX: IMU.4, U1.18 (18(TX1))
unnamed: HEARTBEAT.A, R5.1
unnamed: FORCE_OUTER.1 (RG), R2.2
unnamed: LED_I/P.A, R1.1
unnamed: FORCE_OUTER.8 (RG), R2.1
unnamed: LED_5V.A, R3.1
unnamed: FORCE_INNER.1 (RG), R4.2
unnamed: FORCE_INNER.8 (RG), R4.1
unnamed: FORCE_REAR.1 (RG), VAR_GAIN_R.1 (CCW)
unnamed: FORCE_REAR.8 (RG), VAR_GAIN_R.2 (WIPER)
PROTEC_I/P+: F1.2, MF_+.1, MR_+.1, R1.2, TVS1.C
PWM1: MOTOR_FRONT.1, U1.7
PWM2: MOTOR_REAR.1, U1.9
RESET: RESET.1, U1.RESET
RX2: MOTOR_FRONT.3, U1.17 (17(RX2))
RX3: MOTOR_REAR.3, U1.15 (15(RX3))
SKATE_INDICATE1: LEFT_SKATE_INDICATOR.1, U1.52
SKATE_INDICATE2: RIGHT_SKATE_INDICATOR.1, U1.53
TX2: MOTOR_FRONT.2, U1.16 (16(TX2))
TX3: MOTOR_REAR.2, U1.14 (14(TX3))

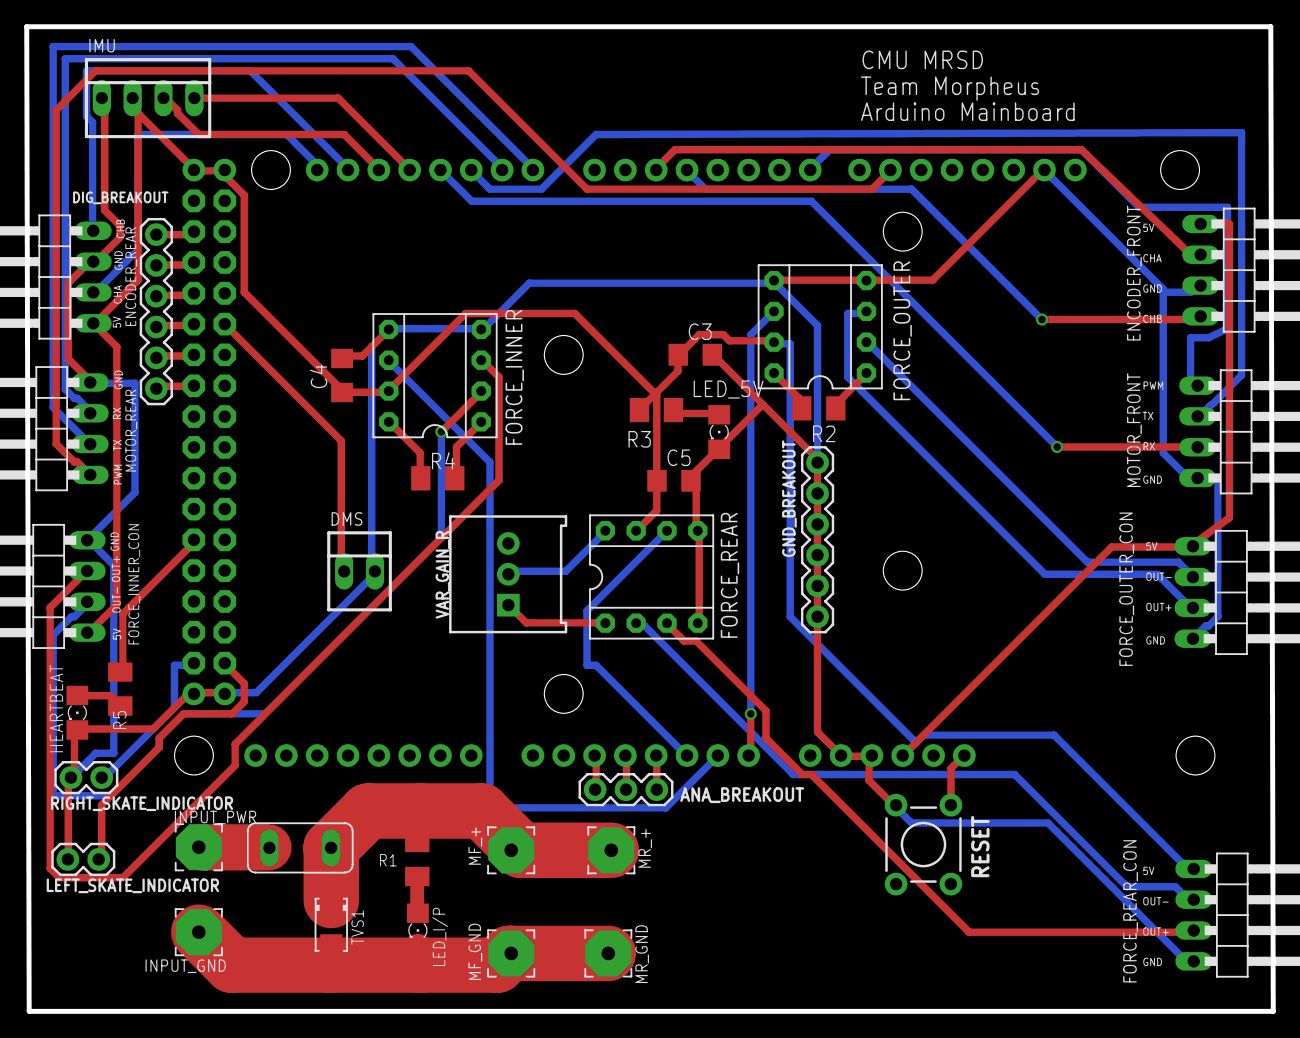
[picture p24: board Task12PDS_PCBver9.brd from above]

Board: 2 copper layers, 102.7 x 81.2 mm, 40 parts (0 on the bottom side), 49 nets.

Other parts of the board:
DRILEGEND: DRILEGEND

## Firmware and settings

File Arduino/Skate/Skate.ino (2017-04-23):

//Revision 4/22/2017
#define LEFT_SKATE_IND_PIN 52
#define RIGHT_SKATE_IND_PIN 53

#define FRC_OUTER_CH 1
#define FRC_INNER_CH 0
#define FRC_REAR_CH 2

#define ENC1_CHA_PIN 2
#define ENC1_CHB_PIN 3

#define ENC2_CHA_PIN 21
#define ENC2_CHB_PIN 20

#define DEAD_MAN_SW_PIN 30
#define HEARTBEAT_PIN 45

#define CTRL_PERIOD_MS 10.0
#define SAMP_PERIOD_MS 2.0
#define ALIVE_PERIOD_MS 500.0

#define SERIAL_BUFFER_SIZE 512
#define TIMEOUT_MS 1000

#include <ros.h>
#include <std_msgs/Float32.h>
#include <std_msgs/Float64.h>
#include <ros/time.h>
#include <morpheus_skates/skate_feedback.h>
#include <morpheus_skates/skate_command.h>
#include "Control.h"
#include "Drive.h"
#include "Force.h"
#include "UM.h"

float target = 0;

long currentTimeStamp = 0;
long lastCtrlTimeStamp = 0;
long lastSampTimeStamp = 0;
long lastAliveTimeStamp = 0;

int global_set_point;
float master_time;
byte skate_fault = 0;
int timeOverrunCnt = 0;
bool controlLoopActive = false;
bool imuRxComplete = false;
bool imuTxComplete = false;

long startTime = 0;

//float posnGainsFront[] = {0.3,0,0};
//float posnGainsRear[] = {0.3,0,0};
float posnGainsFront[] = {0,0,0};
float posnGainsRear[] = {0,0,0};

//float velGainsFront[] = {0,0,0};
//float velGainsRear[] = {0,0,0};
//float velGainsFront[] = {0.001,0.000008,0};
//float velGainsRear[] = {0.001,0.000008,0};

//Critically damped
//float velGainsFront[] = {0.0005,0,0};
//float velGainsRear[] = {0.0005,0,0};
//float velGainsFront[] = {0.0006,0,0};
//float velGainsRear[] = {0.0006,0,0};

//Underdamped
//float velGainsFront[] = {0.001,0,0};
//float velGainsRear[] = {0.001,0,0};

//Unstable
//float velGainsFront[] = {0.002,0,0};
//float velGainsRear[] = {0.002,0,0};

float velGainsFront[] = {0.0006,0.000005,0};
float velGainsRear[] = {0.0006,0.000005,0};

float frontVelCmd;
float frontVelCmdPrev = 0;
float rearVelCmd;
float rearVelCmdPrev = 0;
bool prevFreeWheel = false;

bool leftSkate = false;
bool rightSkate = false;

bool timeoutState = false;
float timeoutVelocity = 0;
bool oneFreeTimeout = true;

//UM7
const byte allRequests[] = {115,110,112,72,109,2,6,115,110,112,76,101,2,2,115,110,112,76,97,1,254};
/*const byte quatRequest[] = {115,110,112,72,109,2,6};
const byte accelRequest[] = {115,110,112,76,101,2,2};
const byte rateRequest[] = {115,110,112,76,97,1,254};*/
//UM6
/*const byte quatRequest[] = {115,110,112,72,100,1,253};
const byte accelRequest[] = {115,110,112,76,94,1,251};
const byte rateRequest[] = {115,110,112,76,92,1,249};*/

void ros_sub_cb(const morpheus_skates::skate_command&);
void formPacket();
void check_reset_system();
void doEncoderFrontChA();
void doEncoderFrontChB();
void doEncoderRearChA();
void doEncoderRearChB();

//Sensor data type and publisher declaration
morpheus_skates::skate_feedback feedback;
ros::Publisher ros_pub_left("left_feedback", &feedback);
ros::Publisher ros_pub_right("right_feedback", &feedback);
ros::Subscriber<morpheus_skates::skate_command> ros_sub_left("left_command", ros_sub_cb);
ros::Subscriber<morpheus_skates::skate_command> ros_sub_right("right_command", ros_sub_cb);
ros::NodeHandle nh;

Force forceSensors(FRC_OUTER_CH,FRC_INNER_CH,FRC_REAR_CH);

Drive frontDrive(ENC1_CHA_PIN,ENC1_CHB_PIN,&Serial2); 
Control frontControl(posnGainsFront,velGainsFront,CTRL_PERIOD_MS);

Drive rearDrive(ENC2_CHA_PIN,ENC2_CHB_PIN,&Serial3);
Control rearControl(posnGainsRear,velGainsRear,CTRL_PERIOD_MS);

UM imu;

void setup() {
  pinMode(LEFT_SKATE_IND_PIN, INPUT_PULLUP);
  pinMode(RIGHT_SKATE_IND_PIN, INPUT_PULLUP);
  if(digitalRead(LEFT_SKATE_IND_PIN) == digitalRead(RIGHT_SKATE_IND_PIN)) {
    while(1);
  }
  if(digitalRead(LEFT_SKATE_IND_PIN) == LOW) {
    leftSkate = true;    
  }
  if(digitalRead(RIGHT_SKATE_IND_PIN) == LOW) {
    rightSkate = true;
  }
  
  //ROS Setup
  nh.initNode();   
  nh.getHardware()->setBaud(115200);
  if(leftSkate == true) {
    nh.advertise(ros_pub_left);
    nh.subscribe(ros_sub_left);
  }
  if(rightSkate == true) {
    nh.advertise(ros_pub_right);
    nh.subscribe(ros_sub_right);
  }

  //Set up Force Sensing
  ADCSRA = bit(ADEN); //turn ADC on
  ADCSRA |= bit (ADPS0) |  bit (ADPS1) | bit (ADPS2);  // Prescaler of 128
  ADMUX  =  bit (REFS0) | (FRC_OUTER_CH & 0x07);    // AVcc and select input port

  //Set Up Front Skate
  attachInterrupt(digitalPinToInterrupt(ENC1_CHA_PIN), doEncoderFrontChA, CHANGE);
  attachInterrupt(digitalPinToInterrupt(ENC1_CHB_PIN), doEncoderFrontChB, CHANGE);
  frontDrive.initializeDrive();
  frontControl.setInvertFlag(leftSkate == true);

  //Set Up Rear Skate
  attachInterrupt(digitalPinToInterrupt(ENC2_CHA_PIN), doEncoderRearChA, CHANGE);
  attachInterrupt(digitalPinToInterrupt(ENC2_CHB_PIN), doEncoderRearChB, CHANGE);
  rearDrive.initializeDrive();
  rearControl.setInvertFlag(leftSkate == true);

  pinMode(DEAD_MAN_SW_PIN, INPUT_PULLUP);
  pinMode(HEARTBEAT_PIN, OUTPUT);

  Serial1.begin(115200);
  Serial1.write(allRequests,21);
}

void loop(){ 
  currentTimeStamp = micros();

  //Sampling Loop
  if((currentTimeStamp - lastSampTimeStamp) >= (SAMP_PERIOD_MS*1000)) {
    lastSampTimeStamp = currentTimeStamp;

    forceSensors.startCycle();
    frontDrive.updateState();
    rearDrive.updateState();
  }

  //Control Loop
  if((currentTimeStamp - lastCtrlTimeStamp) >= (CTRL_PERIOD_MS*1000)) {
    lastCtrlTimeStamp = currentTimeStamp;
    feedback.debug_int3 = (micros() - startTime);
    startTime = micros();
    
    if(controlLoopActive == true) {
      timeOverrunCnt = timeOverrunCnt + 1;
    }

    controlLoopActive = true;

    target = global_set_point;
    check_reset_system();
    frontVelCmdPrev = frontVelCmd;
    rearVelCmdPrev = rearVelCmd;
    if(frontControl.checkModeTransition() == true) frontDrive.resetState();
    if(rearControl.checkModeTransition() == true) rearDrive.resetState();

    if(target > 0) {      
      frontVelCmd = frontControl.computeCommand(target,frontDrive.getPosition(),frontDrive.getVelocity());
      if(frontVelCmdPrev != frontVelCmd) frontDrive.setDutyCycle(frontVelCmd);  
      
      rearVelCmd = rearControl.computeCommand(target,rearDrive.getPosition(),rearDrive.getVelocity());
      if(rearVelCmdPrev != rearVelCmd) rearDrive.setDutyCycle(rearVelCmd);
         
      skate_fault = rearControl.checkErrors();
      skate_fault |= frontControl.checkErrors() << 2;
      skate_fault |= (timeOverrunCnt & 0xF) << 4;
    }
    else {
      frontVelCmd = frontControl.computeCommand(0,frontDrive.getPosition(),frontDrive.getVelocity());
      rearVelCmd = rearControl.computeCommand(0,rearDrive.getPosition(),rearDrive.getVelocity());

      if(target == 0) {
        if(prevFreeWheel == true) {
          frontDrive.setDutyCycle(0.0001);
          rearDrive.setDutyCycle(0.0001);
          prevFreeWheel = false;
        }
        else {
          frontDrive.setDutyCycle(0);
          rearDrive.setDutyCycle(0);
        }
      }
      else {
        frontDrive.setCurrent(0);
        rearDrive.setCurrent(0);
        prevFreeWheel = true;
      }
    }
    
    feedback.debug_int1 = int(micros() - startTime);

    formPacket();
    if(leftSkate == true) {
      ros_pub_left.publish(&feedback);
    }
    if(rightSkate == true) {
      ros_pub_right.publish(&feedback);
    }
    nh.spinOnce();
    feedback.debug_int2 = int(micros() - startTime);
    controlLoopActive = false;
  }

  //Alive Loop
  if((currentTimeStamp - lastAliveTimeStamp) >= (ALIVE_PERIOD_MS*1000)) {
    lastAliveTimeStamp = currentTimeStamp;
    
    frontDrive.resetTimeout();
    rearDrive.resetTimeout();

    digitalWrite(HEARTBEAT_PIN,!digitalRead(HEARTBEAT_PIN));
  }
}

void ros_sub_cb(const morpheus_skates::skate_command& cmd_msg){
  //global_set_point = cmd_msg.command_target*(skate_fault==0);
  if(oneFreeTimeout == true) {
    oneFreeTimeout == false;
    timeoutState = false;
  }
  if(timeoutState == false) {
    global_set_point = cmd_msg.command_target;
  }
  master_time = millis();
}

void formPacket() {
    feedback.header.stamp = nh.now();
  
    feedback.force_front_outer = forceSensors.getAdcOuter();
    feedback.force_front_inner = forceSensors.getAdcInner();
    feedback.force_rear = forceSensors.getAdcRear();

    feedback.velocity_cmd_rear = rearVelCmd; 
    feedback.velocity_cmd_front = frontVelCmd;

    feedback.skate_fault = skate_fault;
    feedback.position_filt_rear = rearDrive.getPosition();
    feedback.position_filt_front = frontDrive.getPosition();

    feedback.velocity_filt_rear = rearDrive.getVelocity();    
    feedback.velocity_filt_front = frontDrive.getVelocity();
    
    feedback.controller_target_rear = rearControl.getControllerTarget();
    feedback.controller_target_front = frontControl.getControllerTarget();

    feedback.skate_mode = frontControl.getMode() + (rearControl.getMode()<<2);

    //Migrate read to control class
    feedback.dead_man_enable = (digitalRead(DEAD_MAN_SW_PIN) == LOW);

    if(imu.updates == 7) {
      imu.updates = 0;
      feedback.debug_int4 = feedback.debug_int4 + 1;
         
      feedback.imu_accel_x = imu.accel_x;
      feedback.imu_accel_y = imu.accel_y;
      feedback.imu_accel_z = imu.accel_z;

      feedback.imu_rate_x = imu.gyro_x;
      feedback.imu_rate_y = imu.gyro_y;
      feedback.imu_rate_z = imu.gyro_z;

      feedback.imu_quat_x = imu.quatA;
      feedback.imu_quat_y = imu.quatB;
      feedback.imu_quat_z = imu.quatC;
      feedback.imu_quat_w = imu.quatD;

      Serial1.write(allRequests,21);
    }

    feedback.debug_float1 = rearControl.getVelocityErrorSum();
    feedback.debug_float2 = frontControl.getVelocityErrorSum();

    //feedback.debug_float1 = rearDrive.getVelocityEncoder();
    //feedback.debug_float2 = frontDrive.getVelocityEncoder();
}

void check_reset_system()
{
  if(millis() - master_time > TIMEOUT_MS) {
    //global_set_point = 0;
    timeoutState = true;
    timeoutVelocity = global_set_point;
  }

  if(timeoutState == true) {
    global_set_point = constrain(global_set_point - timeoutVelocity*(float(CTRL_PERIOD_MS)/(3*1000.0)),0,1000);
  }
}

void doEncoderFrontChA() {
  frontDrive.serviceEncoder(1);
}

void doEncoderFrontChB() {
  frontDrive.serviceEncoder(2);
}

void doEncoderRearChA() {
  rearDrive.serviceEncoder(1);
}

void doEncoderRearChB() {
  rearDrive.serviceEncoder(2);
}

ISR (ADC_vect) {
  //checkAdcReady = forceSensors.serviceSensors(ADC);  
  forceSensors.serviceSensors(ADC); 
}

ISR (USART1_RX_vect) {
  char data;
  data = UDR1;
  imu.encode(data);
}

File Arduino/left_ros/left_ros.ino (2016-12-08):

// ROS Stuff

#define SERIAL_BUFFER_SIZE 256
//#include <Wire.h>
#include <ros.h>
#include <std_msgs/Float32.h>
#include <std_msgs/Float64.h>
#include <sensor_msgs/Temperature.h>
#include <UM.h>
#include <ros/time.h>
//#include <tf/transform_broadcaster.h>
#include <sensor_msgs/Imu.h>
#include <motor/Num.h>
#include <motor/states.h>

#include <motor/yaml_values.h>
int global_state, global_set_point;

float velocityTargetLimPrev = 0;
std_msgs::Float64 myData;
ros::Publisher chatter("c", &myData);

void servo_cb( const motor::states& cmd_msg){

  //servo.write(cmd_msg.data*180.0/100.0); //set servo angle, should be from 0-180 
  //force_msg.data = cmd_msg.data*180.0/100.0;
  //pub_force.publish(&force_msg);
  //servo.write(0);
  //servo.write(cmd_msg.data);
  //if(cmd_msg.data == 30) {
    global_state = cmd_msg.state;
    global_set_point = cmd_msg.set_point;
    
   // digitalWrite(13, HIGH-digitalRead(13));  //toggle led  
 // }

}

ros::Subscriber<motor::states> sub("servo", servo_cb);
    
//Connect the RX pin on the UM7 to TX1 (pin 18) on the DUE
//Connect the TX pin on the UM7 to RX1 (pin 19) on the DUE

UM imu;

float left_bias_f1, left_bias_f2, left_bias_f3, right_bias_f1, right_bias_f2, right_bias_f3, left_gain_f1, left_gain_f2, left_gain_f3, right_gain_f1, right_gain_f2, right_gain_f3;

ros::NodeHandle  nh;

//Set up the ros node and publisher

motor::Num total_sensor;

ros::Publisher left("left", &total_sensor);

ros::ServiceClient<motor::yaml_values::Request, motor::yaml_values::Response> client("yaml_send");

// ROS Stuff ends

#define LEFT_SKATE 0
#define RIGHT_SKATE 1

#define ENC1_CHA_PIN 21
#define ENC1_CHB_PIN 20
#define ESC1_PIN 7 

#define ENC2_CHA_PIN 2
#define ENC2_CHB_PIN 3
#define ESC2_PIN 9

#define ONE_REV_DIST_MM (3.14*2.875*25.4)
#define CPR 360
#define PPR (CPR*4)

#define P_P_GAIN 2
#define P_I_GAIN 0
#define P_D_GAIN 0.4

#define V_P_GAIN 0.01
#define V_I_GAIN 0
#define V_D_GAIN 0

#define ACCEL_LIMIT 100

#define PERIOD_MS 20.0

enum States
{
  Position_Mode,
  Velocity_Mode
};

States system_state = Position_Mode;

#include <Servo.h>

volatile long encCount1 = 0;
volatile long encCount2 = 0;

boolean A1_set = false;
boolean B1_set = false;

boolean A2_set = false;
boolean B2_set = false;

float target = 0;

float skatePosition = 0;
float positionTarget = 0;
float positionError = 0;
float positionErrorSum = 0;
float positionErrorDiff = 0;
float positionErrorPrev = 0;

float skateVelocity = 0;
float skatePositionPrev = 0;
float velocityTarget = 0;
float velocityTargetLim = 0;
float velocityError = 0;
float velocityErrorSum = 0;
float velocityErrorDiff = 0;
float velocityErrorPrev = 0;

float speedCommand = 0;
float esc1Command = 0;
float esc2Command = 0;

long lastTimeStamp = 0;
long currentTimeStamp = 0;

Servo esc1; //Front
Servo esc2; //Back



void setup() {
  
  // ROS Stuff

  nh.initNode();
  nh.advertise(left);    
  nh.getHardware()->setBaud(115200);
  nh.serviceClient(client);
  nh.advertise(chatter);
  Serial1.begin(115200);
  nh.subscribe(sub);
  delay(5000);

  motor::yaml_values::Request req;
  motor::yaml_values::Response resp;
  client.call(req, resp);
  left_bias_f1 = resp.left_bias_f1;
  left_bias_f2 = resp.left_bias_f2;
  left_bias_f3 = resp.left_bias_f3;
  left_gain_f1 = resp.left_gain_f1;
  left_gain_f2 = resp.left_gain_f2;
  left_gain_f3 = resp.left_gain_f3;

  right_bias_f1 = resp.right_bias_f1;
  right_bias_f2 = resp.right_bias_f2;
  right_bias_f3 = resp.right_bias_f3;
  right_gain_f1 = resp.right_gain_f1;
  right_gain_f2 = resp.right_gain_f2;
  right_gain_f3 = resp.right_gain_f3;

  // ROS Stuff ends

  //Set Up Front Skate
  pinMode(ENC1_CHA_PIN, INPUT); 
  pinMode(ENC1_CHB_PIN, INPUT);
  pinMode(ESC1_PIN, OUTPUT);
  attachInterrupt(digitalPinToInterrupt(ENC1_CHA_PIN), doEncoder1A, CHANGE);
  attachInterrupt(digitalPinToInterrupt(ENC1_CHB_PIN), doEncoder1B, CHANGE);


  //Set Up Back Skate
  pinMode(ENC2_CHA_PIN, INPUT); 
  pinMode(ENC2_CHB_PIN, INPUT);
  pinMode(ESC2_PIN, OUTPUT); 
  attachInterrupt(digitalPinToInterrupt(ENC2_CHA_PIN), doEncoder2A, CHANGE);
  attachInterrupt(digitalPinToInterrupt(ENC2_CHB_PIN), doEncoder2B, CHANGE);
 
  //Enable Speed Controllers
  esc1.attach(ESC1_PIN);
  setSpeed(1,0.0); 
  esc2.attach(ESC2_PIN);
  setSpeed(2,0.0);

  //pinMode(50, OUTPUT);

 // Serial.begin(115200);
  //Serial.println("Standby...prepping alcubierre drive");
  delay(8000);
  //Serial.println("Ready to roll!");
}

// ROS stuff
long publisher_timer = 0;
// ROS sutff ends

void loop(){ 

  // ROS Stuff

  if (Serial1.available() > 0) {
     
      if (imu.encode(Serial1.read())) {
         
        
        total_sensor.header.stamp = nh.now();
        

        total_sensor.f1 = analogRead(A0);
        total_sensor.f2 = analogRead(A1);
        total_sensor.f3 = analogRead(A2);
      
        
        total_sensor.ax = imu.accel_x;
        total_sensor.ay = imu.accel_y;
        total_sensor.az = imu.accel_z;
        
       
        total_sensor.rp = imu.gyro_x; 
        total_sensor.ry = imu.gyro_y;
        total_sensor.rr = imu.gyro_z;


        total_sensor.qx = imu.quatx;
        total_sensor.qy =imu.quaty;
        total_sensor.qz =imu.quatz;
        total_sensor.qw = imu.quatw;


        left.publish(&total_sensor);
           
    }
  }
   
 

  // ROS Stuff ends
  
  currentTimeStamp = millis();

  
  if((currentTimeStamp - lastTimeStamp) >= PERIOD_MS) {
    //digitalWrite(50,!digitalRead(50));
    lastTimeStamp = currentTimeStamp;
    
     
    chatter.publish( &myData );
    target = global_set_point;
    //If the target velocity is 0 and the velocity is low enough, switch to position control
    if((target == 0) && (abs(skateVelocity) < 50) && (system_state == Velocity_Mode)) {
      system_state = Position_Mode;
      encCount1 = 0;
      encCount2 = 0;
      positionErrorSum = 0;
      velocityErrorSum = 0;
    }

    //If the target velocity is not 0, switch to velocity control
    if((target != 0) && (system_state == Position_Mode)) {
      system_state = Velocity_Mode;
      encCount1 = 0;
      encCount2 = 0;
      positionErrorSum = 0; 
      velocityErrorSum = 0;
    }

    //Common Mode Information
    skatePositionPrev = skatePosition;
    skatePosition = ((0.5*float(encCount1 + encCount2)) / PPR) * ONE_REV_DIST_MM;
    
    //Position Control
    if(system_state == Position_Mode) {  
      positionTarget = target;
         
      positionErrorPrev = positionError;
      positionError = positionTarget - skatePosition;
      positionErrorSum = positionErrorSum + positionError;
      positionErrorDiff = positionError - positionErrorPrev;
      
      speedCommand = P_P_GAIN*positionError + P_I_GAIN*positionErrorSum + P_D_GAIN*positionErrorDiff;
      speedCommand = constrain(speedCommand,-90,90);
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

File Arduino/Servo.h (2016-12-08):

/*
  Servo.h - Interrupt driven Servo library for Arduino using 16 bit timers- Version 2
  Copyright (c) 2009 Michael Margolis.  All right reserved.

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
  You should have received a copy of the GNU Lesser General Public
  License along with this library; if not, write to the Free Software
  Foundation, Inc., 51 Franklin St, Fifth Floor, Boston, MA  02110-1301  USA
*/

/* 
  A servo is activated by creating an instance of the Servo class passing 
  the desired pin to the attach() method.
  The servos are pulsed in the background using the value most recently 
  written using the write() method.

  Note that analogWrite of PWM on pins associated with the timer are 
  disabled when the first servo is attached.
  Timers are seized as needed in groups of 12 servos - 24 servos use two 
  timers, 48 servos will use four.
  The sequence used to sieze timers is defined in timers.h

  The methods are:

    Servo - Class for manipulating servo motors connected to Arduino pins.

    attach(pin )  - Attaches a servo motor to an i/o pin.
    attach(pin, min, max  ) - Attaches to a pin setting min and max values in microseconds
    default min is 544, max is 2400  
 
    write()     - Sets the servo angle in degrees.  (invalid angle that is valid as pulse in microseconds is treated as microseconds)
    writeMicroseconds() - Sets the servo pulse width in microseconds 
    read()      - Gets the last written servo pulse width as an angle between 0 and 180. 
    readMicroseconds()   - Gets the last written servo pulse width in microseconds. (was read_us() in first release)
    attached()  - Returns true if there is a servo attached. 
    detach()    - Stops an attached servos from pulsing its i/o pin. 
 */

#ifndef Servo_h
#define Servo_h

#include <inttypes.h>

/* 
 * Defines for 16 bit timers used with  Servo library 
 *
 * If _useTimerX is defined then TimerX is a 16 bit timer on the current board
 * timer16_Sequence_t enumerates the sequence that the timers should be allocated
 * _Nbr_16timers indicates how many 16 bit timers are available.
 */

// Architecture specific include
#if defined(ARDUINO_ARCH_AVR)
#include "avr/ServoTimers.h"
#elif defined(ARDUINO_ARCH_SAM)
#include "sam/ServoTimers.h"
#elif defined(ARDUINO_ARCH_SAMD)
#include "samd/ServoTimers.h"
#else
#error "This library only supports boards with an AVR, SAM or SAMD processor."
#endif

#define Servo_VERSION           2     // software version of this library

#define MIN_PULSE_WIDTH       544     // the shortest pulse sent to a servo  
#define MAX_PULSE_WIDTH      2400     // the longest pulse sent to a servo 
#define DEFAULT_PULSE_WIDTH  1500     // default pulse width when servo is attached
//#define REFRESH_INTERVAL    20000     // minumim time to refresh servos in microseconds 
//#define REFRESH_INTERVAL    10000     // minumim time to refresh servos in microseconds 
//#define REFRESH_INTERVAL    5000     // minumim time to refresh servos in microseconds 
#define REFRESH_INTERVAL    4000     // minumim time to refresh servos in microseconds 

#define SERVOS_PER_TIMER       12     // the maximum number of servos controlled by one timer 
#define MAX_SERVOS   (_Nbr_16timers  * SERVOS_PER_TIMER)

#define INVALID_SERVO         255     // flag indicating an invalid servo index

typedef struct  {
  uint8_t nbr        :6 ;             // a pin number from 0 to 63
  uint8_t isActive   :1 ;             // true if this channel is enabled, pin not pulsed if false 
} ServoPin_t   ;  

typedef struct {
  ServoPin_t Pin;
  volatile unsigned int ticks;
} servo_t;

class Servo
{
public:
  Servo();
  uint8_t attach(int pin);           // attach the given pin to the next free channel, sets pinMode, returns channel number or 0 if failure
  uint8_t attach(int pin, int min, int max); // as above but also sets min and max values for writes. 
  void detach();
  void write(int value);             // if value is < 200 its treated as an angle, otherwise as pulse width in microseconds 
  void writeMicroseconds(int value); // Write pulse width in microseconds 
  int read();                        // returns current pulse width as an angle between 0 and 180 degrees
  int readMicroseconds();            // returns current pulse width in microseconds for this servo (was read_us() in first release)
  bool attached();                   // return true if this servo is attached, otherwise false 
private:
   uint8_t servoIndex;               // index into the channel data for this servo
   int8_t min;                       // minimum is this value times 4 added to MIN_PULSE_WIDTH    
   int8_t max;                       // maximum is this value times 4 added to MAX_PULSE_WIDTH   
};

#endif

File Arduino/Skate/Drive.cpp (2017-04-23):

/*
  Drive.cpp - Library for drive train interfacing
*/

#include "Arduino.h"
#include "Drive.h"
#include "buffer.h"
#include "crc.h"


Drive::Drive(int ECA_pin,int ECB_pin,HardwareSerial* port) {
  encChaPin = ECA_pin;
  encChbPin = ECB_pin;
  serial = port;
  
  commandLim = 0;

  A_set = false;
  B_set = false;
  resetState();

  lastUpdateTime = micros();
}

void Drive::initializeDrive() {
  pinMode(encChaPin, INPUT); 
  pinMode(encChbPin, INPUT);
  serial->begin(115200);
  setDutyCycle(0);  
}


void Drive::serviceEncoder(int chId) {
  switch(chId) {
    case 1:
      A_set = digitalRead(encChaPin) == HIGH;     
      encCount += (A_set != B_set) ? +1 : -1; //increment counter if A leads B
      break;
    case 2:
      B_set = digitalRead(encChbPin) == HIGH;
      encCount += (A_set == B_set) ? +1 : -1;  //increment counter if B follows A
      break;
  }
}


void Drive::updateState(){
  updateTimeDelta = micros() - lastUpdateTime;
  lastUpdateTime = micros();

  float dt, wheelPositionError;
  dt = (float)updateTimeDelta/(1000000);
  wheelPositionEncoderPrev = wheelPositionEncoder;
  wheelPositionEncoder = (float(encCount) / PPR) * ONE_REV_DIST_MM;
  wheelVelocityEncoder = (wheelPositionEncoder - wheelPositionEncoderPrev)/dt;
  
  wheelPositionEstimate = wheelPositionEstimate + wheelVelocityEstimate*dt;
  wheelPositionError = wheelPositionEncoder - wheelPositionEstimate;
  wheelVelocityInteg = wheelVelocityInteg + wheelPositionError*KI*dt;
  wheelVelocityEstimate = wheelPositionError*KP + wheelVelocityInteg;
}


void Drive::resetState() {
  encCount = 0;
  wheelPositionEncoder = 0;
  wheelPositionEncoderPrev = 0;
  wheelPositionEstimate = 0;
  wheelVelocityEncoder = 0;
  wheelVelocityInteg = 0;
  wheelVelocityEstimate = 0; 
}


float Drive::getPosition() {
  return wheelPositionEstimate;
}


float Drive::getVelocity() {
  return wheelVelocityEstimate;
}

float Drive::getVelocityEncoder() {
  return wheelVelocityEncoder;
}


void Drive::setDutyCycle(float dutyCycle) {
  unsigned short crc;
  sendIndex = 0;
  
  sendBuffer[sendIndex++] = COMM_SET_DUTY;
  buffer_append_float32(sendBuffer, dutyCycle, 100000.0, &sendIndex);
  crc = crc16(sendBuffer,sendIndex);
  buffer_append_uint16(sendBuffer, crc, &sendIndex);

  sendCommand();
}


void Drive::setCurrent(float current) {
  unsigned short crc;
  sendIndex = 0;

  sendBuffer[sendIndex++] = COMM_SET_CURRENT;
  buffer_append_float32(sendBuffer, current, 1000.0, &sendIndex);  
  crc = crc16(sendBuffer,sendIndex);
  buffer_append_uint16(sendBuffer, crc, &sendIndex);

  sendCommand();
}


void Drive::resetTimeout() {
  unsigned short crc;
  sendIndex = 0;

  sendBuffer[sendIndex++] = COMM_ALIVE;
  crc = crc16(sendBuffer,sendIndex);
  buffer_append_uint16(sendBuffer, crc, &sendIndex);

  sendCommand();
}


void Drive::sendCommand() {
  serial->write(2);
  serial->write(sendIndex-2);
  serial->write(sendBuffer,sendIndex);
  serial->write(3);
}

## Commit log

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2016-11-29 "new ros codes"
    [calibration_values.yaml]
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2016-12-01 not working, but compiling arduino
    [velocity_control_ros.ino]
2016-12-07 Add files via upload
    Uploading latest low_level_controller with working position and velocity control. Copy the Servo.h to your local Servo library folder to enable higher speed PWM outputs.
2017-01-26 Updated ROS Arduino code to correct encoder velocity calculation. - Requires testing
    [ros_working_arduino.ino]
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2017-01-27 fixed a bug in the calibration routine
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2017-02-01 push for code transition
    [calibration_values.yaml]
2017-02-05 adding MRSD packages, as I had used it to show the IMU during one PR
2017-02-06 Added serial_motor_commander which accepts a command -100 to +100, maps it to the appropriate pwm command, drives the speed controller, and returns the encoder value.
2017-02-08 heartbeat tetsed
    [ImuFilterMadgwick.cfg, OpenNI.cfg]
2017-02-12 changed nomenclature
    [calibration_values.yaml]
2017-02-18 untested code
    [calibration_values.yaml]
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2017-02-18 Added initial keywords.txt for function highlighting, but updates required.
    Added updated mechanical drawing of the aux shaft.
    [ss_mf_v1_AuxShaft.SLDDRW]
2017-02-19 Effectively merging test into Factor by replacing src and removing install, etc
    [calibration_values.yaml]
2017-02-20 Started debugging class-based Arduino code, syntax errors and such
    [Drive.cpp, Drive.h, Skate.ino]
2017-02-22 Initial debugging of class-based Arduino code. Position control works on Left Skate. Currently fighting with velocity control - pulsing behavior. Added numerous debugging outputs through ROS. Modifie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
2017-02-24 Completed initial debugging and development of object-based code. Controls still needs work but performs reasonably under load or at speeds of 200 or higher. Replaced moving average filters with trac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
    [Drive.cpp, Drive.h, Skate.ino]
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2017-02-25 Updated Arduino code to reintegrate IMU - requires testing. IMU cpp and h moved into Skate folder to resolve compilation issue.
    [Skate.ino]
2017-02-25 Corrected IMU request for acceleration
    [Skate.ino]
2017-02-26 working normalization
    [calibration_values.yaml]
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2017-02-27 Changes to IMU messaging to account for the fact that serialEvent is actually polling not interrupt based. Slight cleanup in UM.cpp.
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2017-02-28 Arduino code with working, lower rate IMU communication. Also wrote serial sniffer that allows an Arduino to forward and rebroadcast bidirectional serial communication allowing for monitoring from a 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
2017-02-28 Mounts for new PCB location over user's toe-box
    [ArduinoMountLeft.SLDPRT, ArduinoMountRight.SLDPRT, GuideRailFL.SLDPRT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]
2017-03-10 Intermediate commit wih 115,200 baud rate to resolve checksum errors. Trying to increase IMU and control loop rates.
    [Skate.ino]
2017-03-10 Achieved best balance of rates and capabilities. Control: 100Hz, IMU: 20Hz, Force: 500Hz
2017-03-11 Corrected mistake in force reading - thanks Saurabh!
    [Force.cpp, Skate.ino]
2017-03-11 Added CAD files for Force Sensor Calibration Rig
    [90283A831_ZINC-PLTD STL PAN HEAD SLOTTED MACHINE SCREW.SLDPRT, 91841A195_TYPE 18-8 STAINLESS STEEL HEX NUT.SLDPRT, 92141A031_TYPE 18-8 STAINLESS STEEL FLAT WAS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]
2017-03-12 adding rest of the files
    [calibration_values.yaml]
2017-03-12 Updates while calibrating. Pounds_display now works.
    [calibration_values.yaml]
2017-03-13 Added matlab script development bag. Pounds display message and related changes from yesterday. Cleanup changes from yesterday. Corrections to stepping_stones.py after testing.
    [calibration_values.yaml]
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2017-03-15 Added rear terminal holder. Housekeeping of moving files to new spring folder.
    [ss_ms_v1_ESC.SLDPRT, ss_ms_v1_rear_terminal_holder.SLDPRT, ss_ms_v1_rear_terminal_holder.STL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]
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2017-03-19 Created DriveCharacterization sketch to perform open loop motor testing with the VESC-X's. Initial code written, some debugging required for compilation.
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2017-03-20 Valid calibration values for all sensors with preload! Update Skate to pull-up digital inputs for skate indicators.
    [calibration_values.yaml]
2017-03-20 Compilation errors resolved for the DriveCharacterization sketch. Functional testing still required.
    [Drive.cpp, Drive.h, DriveCharacterization.ino]
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2017-03-21 Updated DriveCharacterization from first level of functional debugging. Ready to test with VESC-X.
2017-03-21 Mounts over user's toe-box for new PCB and the IMU
    [ArduinoMountLeft_v2.SLDPRT, ArduinoMountRight_v2.SLDPRT]
2017-03-22 Added MAT files from static ground truth experiments. Modified DriveCharacterization for start signal.
2017-03-22 Wrote script to combine normalized force readings from an experiment. Converted stance tests to mat and csv with script.
    [stance_tests_20th_march.csv]
2017-03-22 Swapped front and rear encoder pin definitions to match new PCB.
    [Skate.ino]
2017-03-23 Migrated VESC-X code from DriveCharacterization to Skate. Updated controls code with preliminary feedforward and feedback elements/gains. Benchtop testing required.
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2017-03-27 Control updates to handle skate directionality. Successfully tested all 4 motors with this code.
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2017-03-30 Updates to parseRosbag for command and feedback message changes. Added integrated message but currently results in java memory error. Parsed multiple messages from last rosBag from plotting - noted e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
2017-03-31 Added tf listeners for other Kinect keypoints with print statements to test using stepping stones, success. Silenced repetitive messages for skate faults and timouts. Changed force normalization to u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
2017-04-04 Open loop motor testing - potential rear left encoder problem and screw interference seized rear right motor in last test.
2017-04-04 Added Matlab ros msg gen stuff including duplication of workspace..sorry
    [calibration_values.yaml]
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2017-04-05 Arduino code with tuned closed loop PI control. Control loop testing ros bags. Added time to total_message header.
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2017-04-07 Updated DriveCharacterization with revised encoder mapping for new PCB. Updated parseRosbag to parse total message. Completed parsing of first rosbag to .mat and .csv files.
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2017-04-08 Added Keystrokes MSVS project with updates for velocity discretization in the VR PC.
2017-04-09 Parsed rosbags of tests from Saturday night. Finally committing V2 of bearing mount 3D printed part.
    [ss_mf_v2_BearingMount.SLDPRT, ss_mf_v2_BearingMount.STL, velocity_saurabh_200_2017-04-09-00-34-12.csv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]
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2017-04-12 Updated Arduino code with reduced Ki for tracking loop, new open loop gain, and unloaded Kp and Ki. Also included fix for state changes of brake and freewheeling. Updated stepping stones to remap lef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
    [Drive.cpp, Drive.h, Skate.ino]
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2017-04-13 Initial version of wheel mount - need to correct hole locations and height.
    [ss_ms_v1_RearWheelFork.SLDPRT]
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2017-04-16 Parsed rosbags from 4/15/2017 evening tests.
    [2017-04-01-23-42-11.csv, Saurabh_100.csv, Saurabh_200.csv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]
2017-04-17 rosbags with HDM
    [calibration_values.yaml]
2017-04-18 Latest parsed rosbags. Initial comEstimator trial code. Updates to caster replacement CAD and STL files.
    [ss_ms_v0_DowelPinShaft.SLDPRT, ss_ms_v1_RearWheelFork.SLDPRT, ss_ms_v1_SkateWheelFork.SLDPRT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]
2017-04-22 kinect based velocity control
    [calibration_values.yaml]
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2017-04-22 Board and Schematic Spring 2017
    [Task12PDS_PCBver9.brd, Task12PDS_PCBver9.sch]
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

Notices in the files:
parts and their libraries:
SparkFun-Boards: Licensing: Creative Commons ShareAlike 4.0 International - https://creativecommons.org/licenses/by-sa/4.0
